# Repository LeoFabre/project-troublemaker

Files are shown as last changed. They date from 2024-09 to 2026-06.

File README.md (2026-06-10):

# 🚨PROJECT TROUBLEMAKER🚨 - ABANDONED, new project coming very soon
### The original dub soundsystem-style, fully digital, open source music preamp, based on ELK Audio OS.

This project is meant to be a fully digital sound system preamp, with a lot of features and a lot of fun to use. 
This would typically be used in a dub sound system control tower, right before the DSPs and power amps.
I am making it for [my own dub sound system](https://linktr.ee/mooncrownsoundsystem), but I am sharing it with the world so that everyone can enjoy and contribute to it.

### **_[Figma design of the front plate (click to open in figma) :](https://www.figma.com/design/a7w33TZh6XjIDETXx0zezs/PROJECT-TROUBLEMAKER?node-id=2-57&t=kPiumWiky9OcTQFE-1)_**
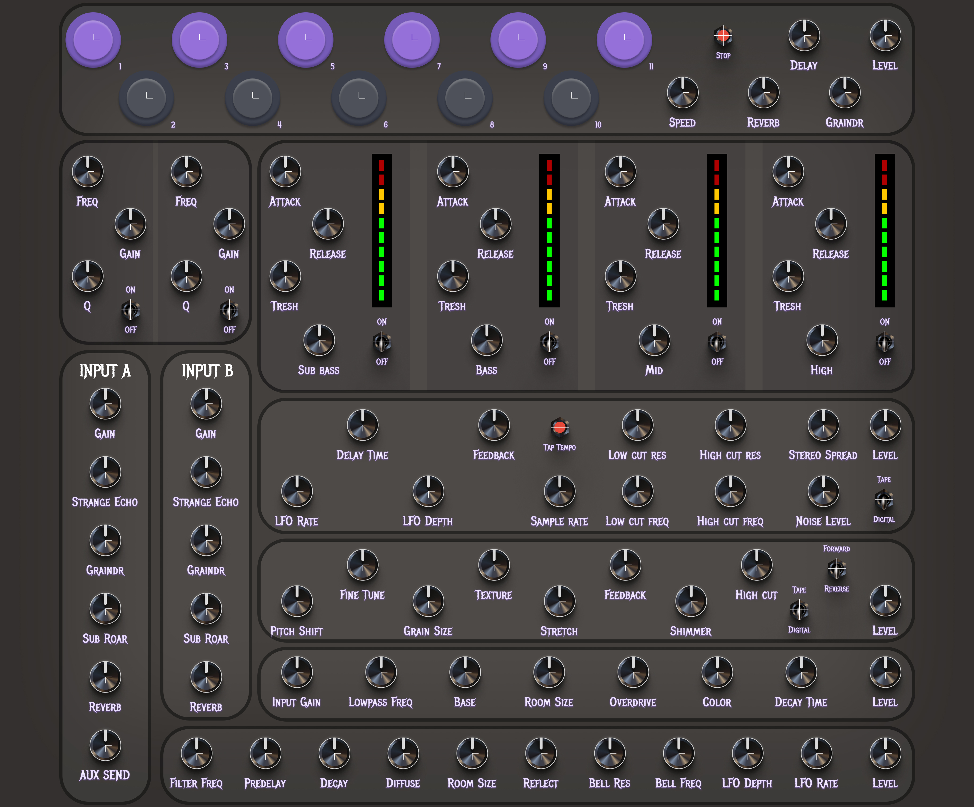
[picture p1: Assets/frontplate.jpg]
(https://www.figma.com/design/a7w33TZh6XjIDETXx0zezs/PROJECT-TROUBLEMAKER?node-id=2-57&t=kPiumWiky9OcTQFE-1)


Please note that this project is still in its early stages, and it is not yet ready for use.
Also, the aim is not to provide a classic preamp to use with a microphone, but rather a preamp to use with a line-level signal, like a CD player, a computer, a synthesizer, etc.
It will NOT provide any protection for your speakers, and also will not split the signal into multiple bands outputs. 

It is meant to be used with a DSP that can handle multiple outputs, and optionally a mixer before it, to get microphone inputs and other line-level inputs.

**At the moment, the inputs and outputs are stereo only**, but more input modes will be added in the future (see Signal Flow section).

# [Software & Hardware stack (Click to open in whimsical)](https://whimsical.com/project-troublemaker-project-diagram-5eJmr8VAKfvCzGg2v3uwR2)
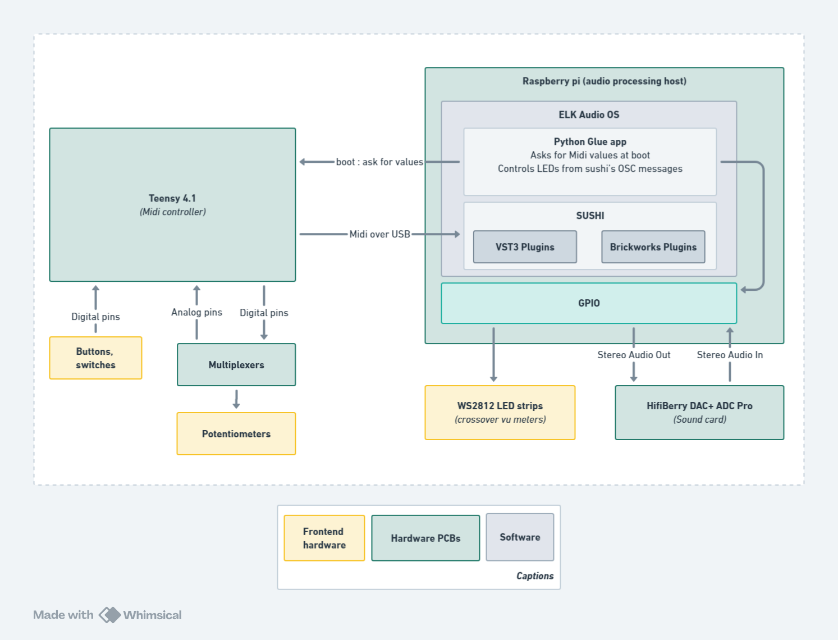
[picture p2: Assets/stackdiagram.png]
(https://whimsical.com/project-troublemaker-project-diagram-5eJmr8VAKfvCzGg2v3uwR2)

Project Troublemaker is based on [ELK Audio OS](https://elk-audio.github.io/elk-docs/html/index.html), which is a Linux-based realtime audio OS that can run VST3 plugins.  
It is **_HIGHLY RECOMMENDED_** to get a grasp of ELK Audio OS before diving into this project.

I use a [Raspberry pi 4 (8GB)](https://www.raspberrypi.com/products/raspberry-pi-4-model-b/) as the main board, 

a [HifiBerry DAC+ ADC Pro](https://www.hifiberry.com/shop/boards/hifiberry-dac-adc-pro/), to get audio I/O,

a [Teensy 4.1](https://www.pjrc.com/store/teensy41.html) as the control board, which acts as a MIDI controller and communicates with the Raspberry Pi via USB.

To build the control panel I use [CD74HC4067 multiplexers](https://www.amazon.fr/ICQUANZX-CD74HC4067-Analogique-Multiplexeur-Num%C3%A9rique/dp/B07VF14YNG), and a lot of [arcade buttons](https://www.smallcab.net/sanwa-obsc-24mm-translucent-pushbutton-purple-p-2462.html), [potentiometers](https://www.amazon.fr/dp/B07B64MWRF?ref=ppx_yo2ov_dt_b_fed_asin_title), [RGB LED sticks](https://fr.aliexpress.com/item/1005006344542138.html), and [switches](https://amazon.fr/dp/B09W4HBXJ7).

The project is meant to be a fully open source project, with all the source code and hardware design files available for free.

**_Because I strongly believe that music is meant to be shared, and music gear should be open source._**

Please feel free to contribute by opening a PR or an issue. 

**_Keep in mind that I am still learning, and that I am doing this project in my free time_**, so I may take some time to get back to you and updates may be slow.

# Featured Plugins (Work in Progress)
- **_[SampleTower](https://github.com/LeoFabre/SampleTower)_** : My JUCE-based VST3 sample player. features 11 fully-loaded-in-RAM sample slots, real-time playback speed control, sample loading from the file system (via config file), sample triggering with a MIDI note, one-shot and loop modes for each sample (via config file), kill button that stops all currently playing samples.
- 2 parametric EQs with bypass switches.
- **_[Moses](https://github.com/LeoFabre/Moses)_** : My fork of [IEM's multiband compressor](https://git.iem.at/audioplugins/IEMPluginSuite/-/tree/master/MultiBandCompressor?ref_type=heads). It is a 4-band SIMD optimized multiband compressor/crossover plugin, featuring cascaded Butterworth, linkwitz-riley filters and Allpass filters, solo&kill switches and master controls.
- **_[Strange Returns](https://github.com/LeoFabre/StrangeReturns-CMake)_** : My fork of JackWithOneEye's [Strange Returns](https://github.com/JackWithOneEye/StrangeReturns) delay plugin. 
- **_[Graindr](https://github.com/LeoFabre/Graindr)_** : My fork of JackWithOneEye's [Graindr](https://github.com/JackWithOneEye/Graindr), dual granular delay plugin.
- **_Parametric Reverb FX_** : A parametric reverb that I have yet to design. The reverb pots on the frontplate are inspired by ableton's reverb plugin, and are subject to change.
- **_Sub Roar FX_** : A classic dub sub bass roar effect based on saturation, and filtering, and reverb. It is only composed of BrickWorks plugins that ELK Audio OS provides, I may or may not make a JUCE version of it in the future.

# [Signal Flow (click to open in whimsical)](https://whimsical.com/project-troublemaker-signal-flow-PksJ2XxrEqBQ8Brrcc3UFW)
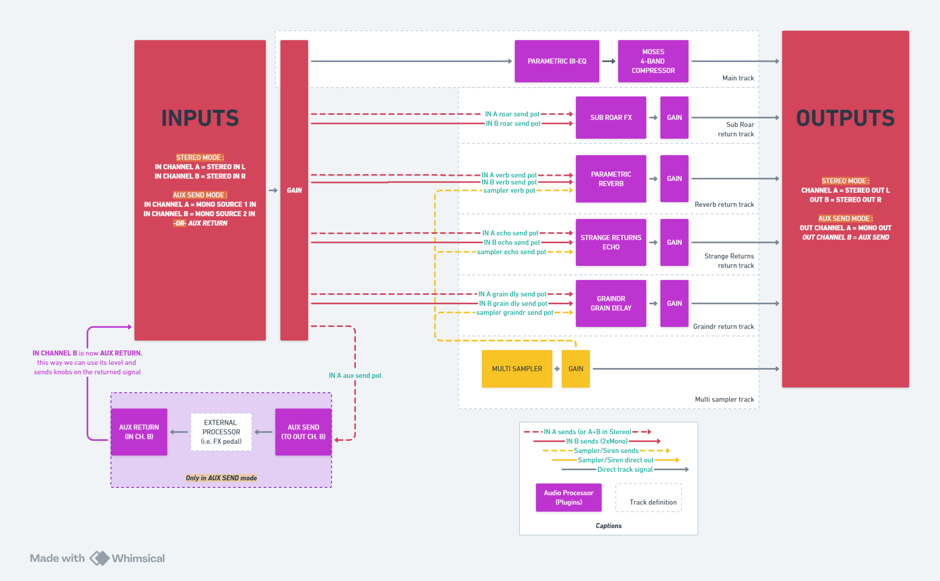
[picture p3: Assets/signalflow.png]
(https://whimsical.com/project-troublemaker-signal-flow-PksJ2XxrEqBQ8Brrcc3UFW)

## Input modes
- **_Stereo mode_**: The default mode, where the HifiBerry is used as a stereo input and output.
- **_Aux send mode_** (to be implemented): The 2 stereo channels of the HifiBerry are split in 2 mono input channels and 2 mono output channels.   
The first mono input channel is used as the main input, the first mono output is used as the main output, the second mono input channel is used as the aux send, and the second mono input channel is used as the aux return.   
This is useful to send the signal to an external effect processor and get it back in the preamp, like a reverb or a delay, and then use the preamp's processing on it.

As of now, the modes are not implemented, and the preamp only works in stereo mode.  
In the future, I will add a switch to select the input mode at boot time (Sushi would then get its processor graph built by the glue app via gRPC instead of the config file).

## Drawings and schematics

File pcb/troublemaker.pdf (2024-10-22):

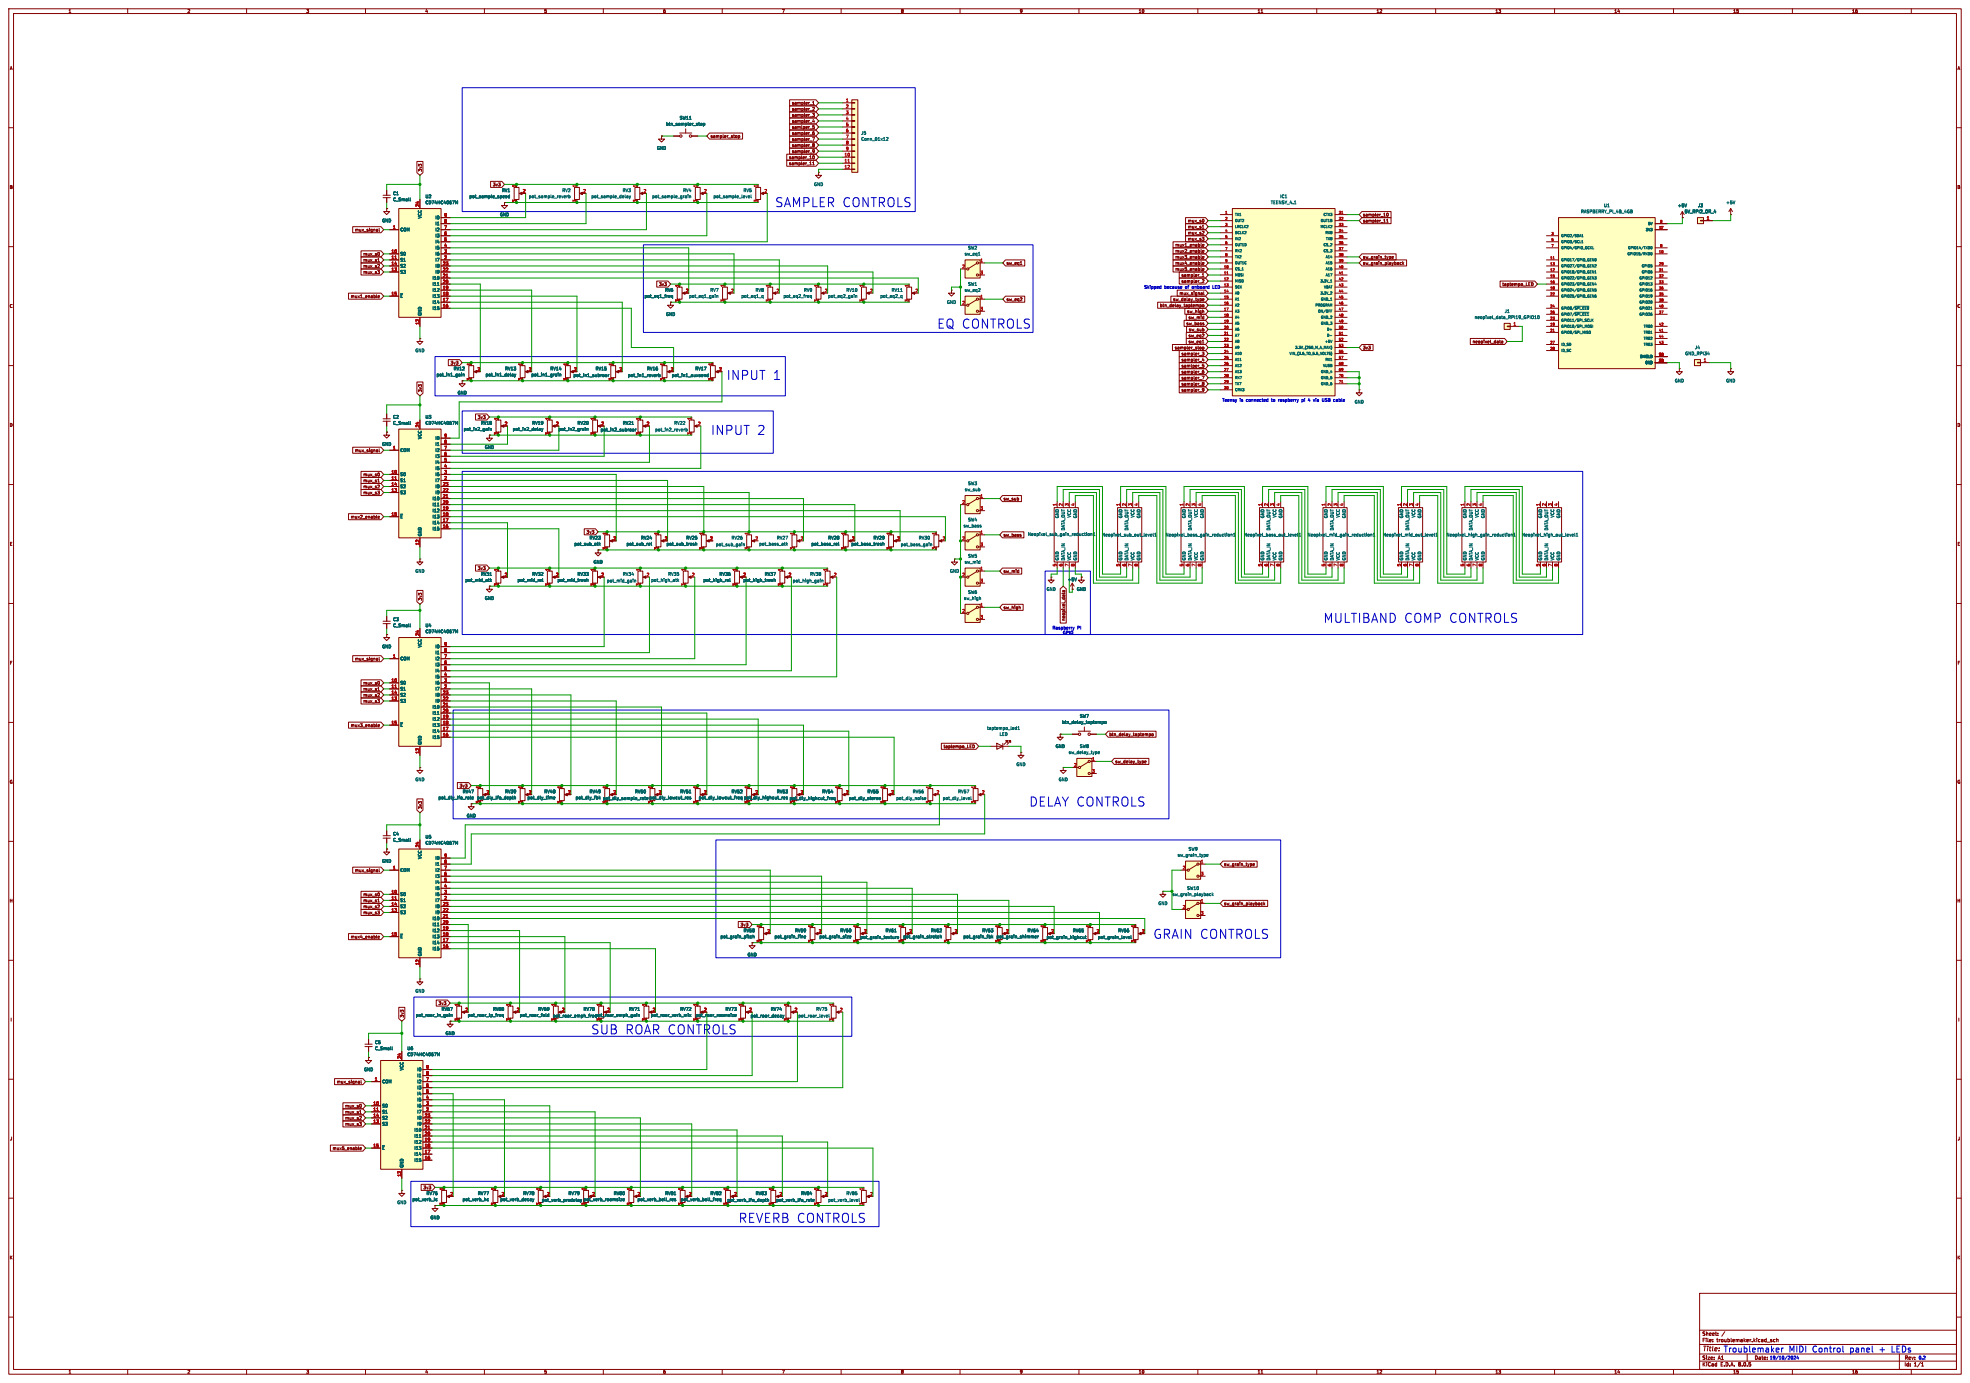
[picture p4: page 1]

Skipped because of onboard LED SUB ROAR CONTROLS

Id: 1/1 Title: File: troublemaker.kicad_sch Sheet: / 1

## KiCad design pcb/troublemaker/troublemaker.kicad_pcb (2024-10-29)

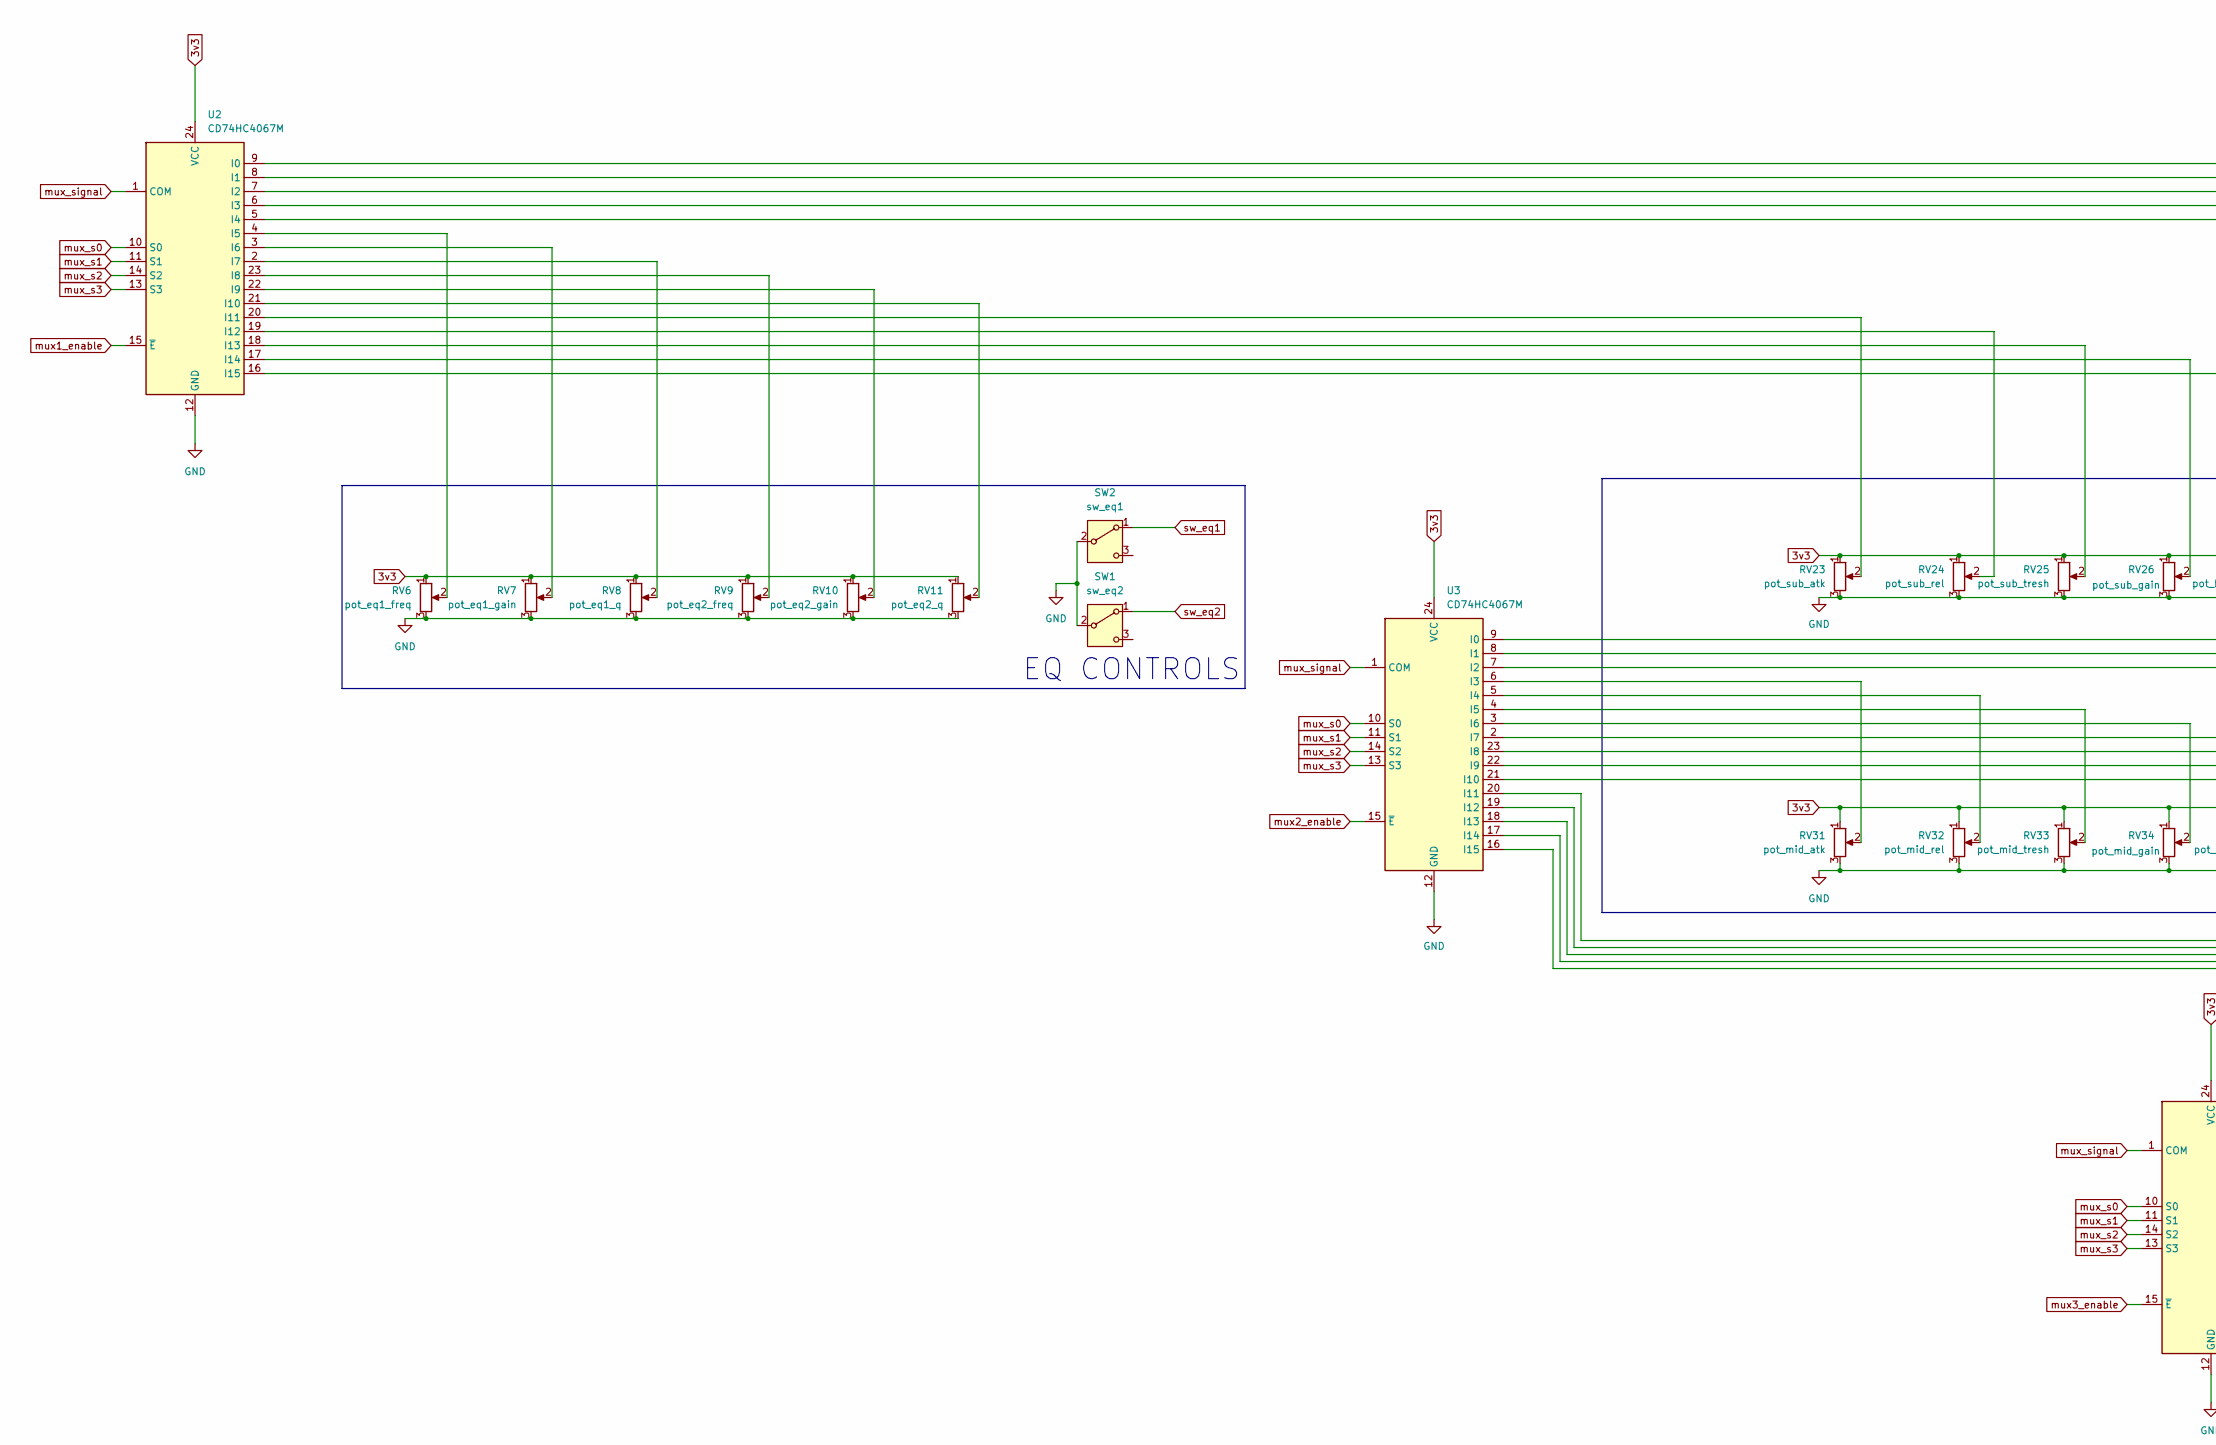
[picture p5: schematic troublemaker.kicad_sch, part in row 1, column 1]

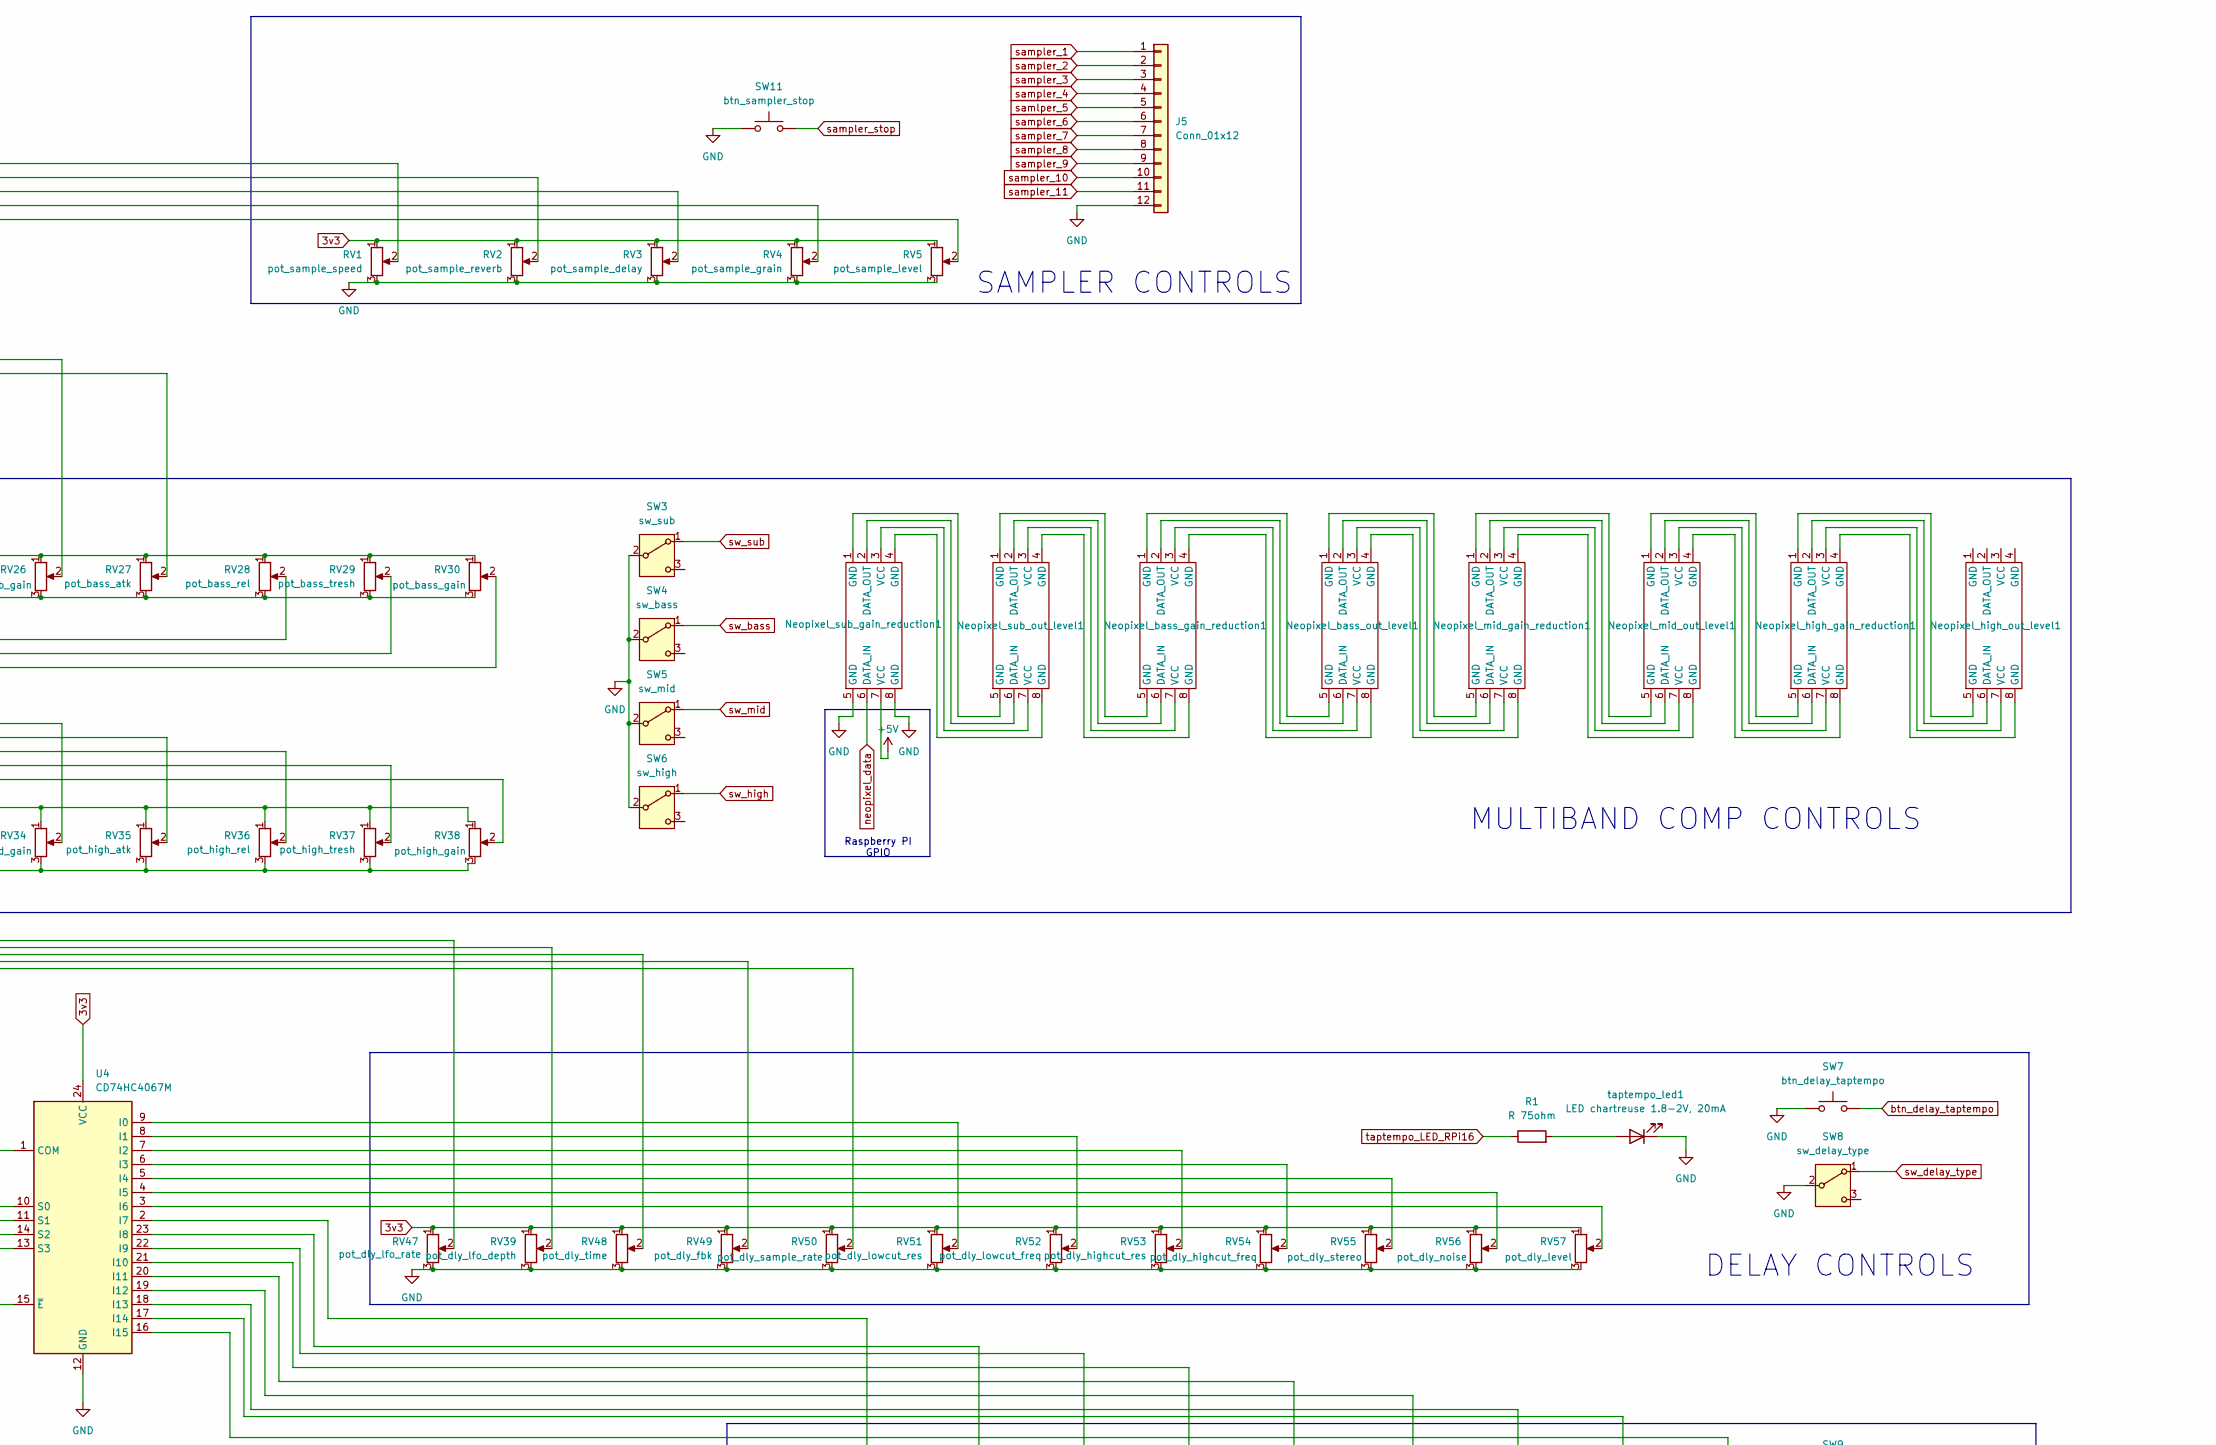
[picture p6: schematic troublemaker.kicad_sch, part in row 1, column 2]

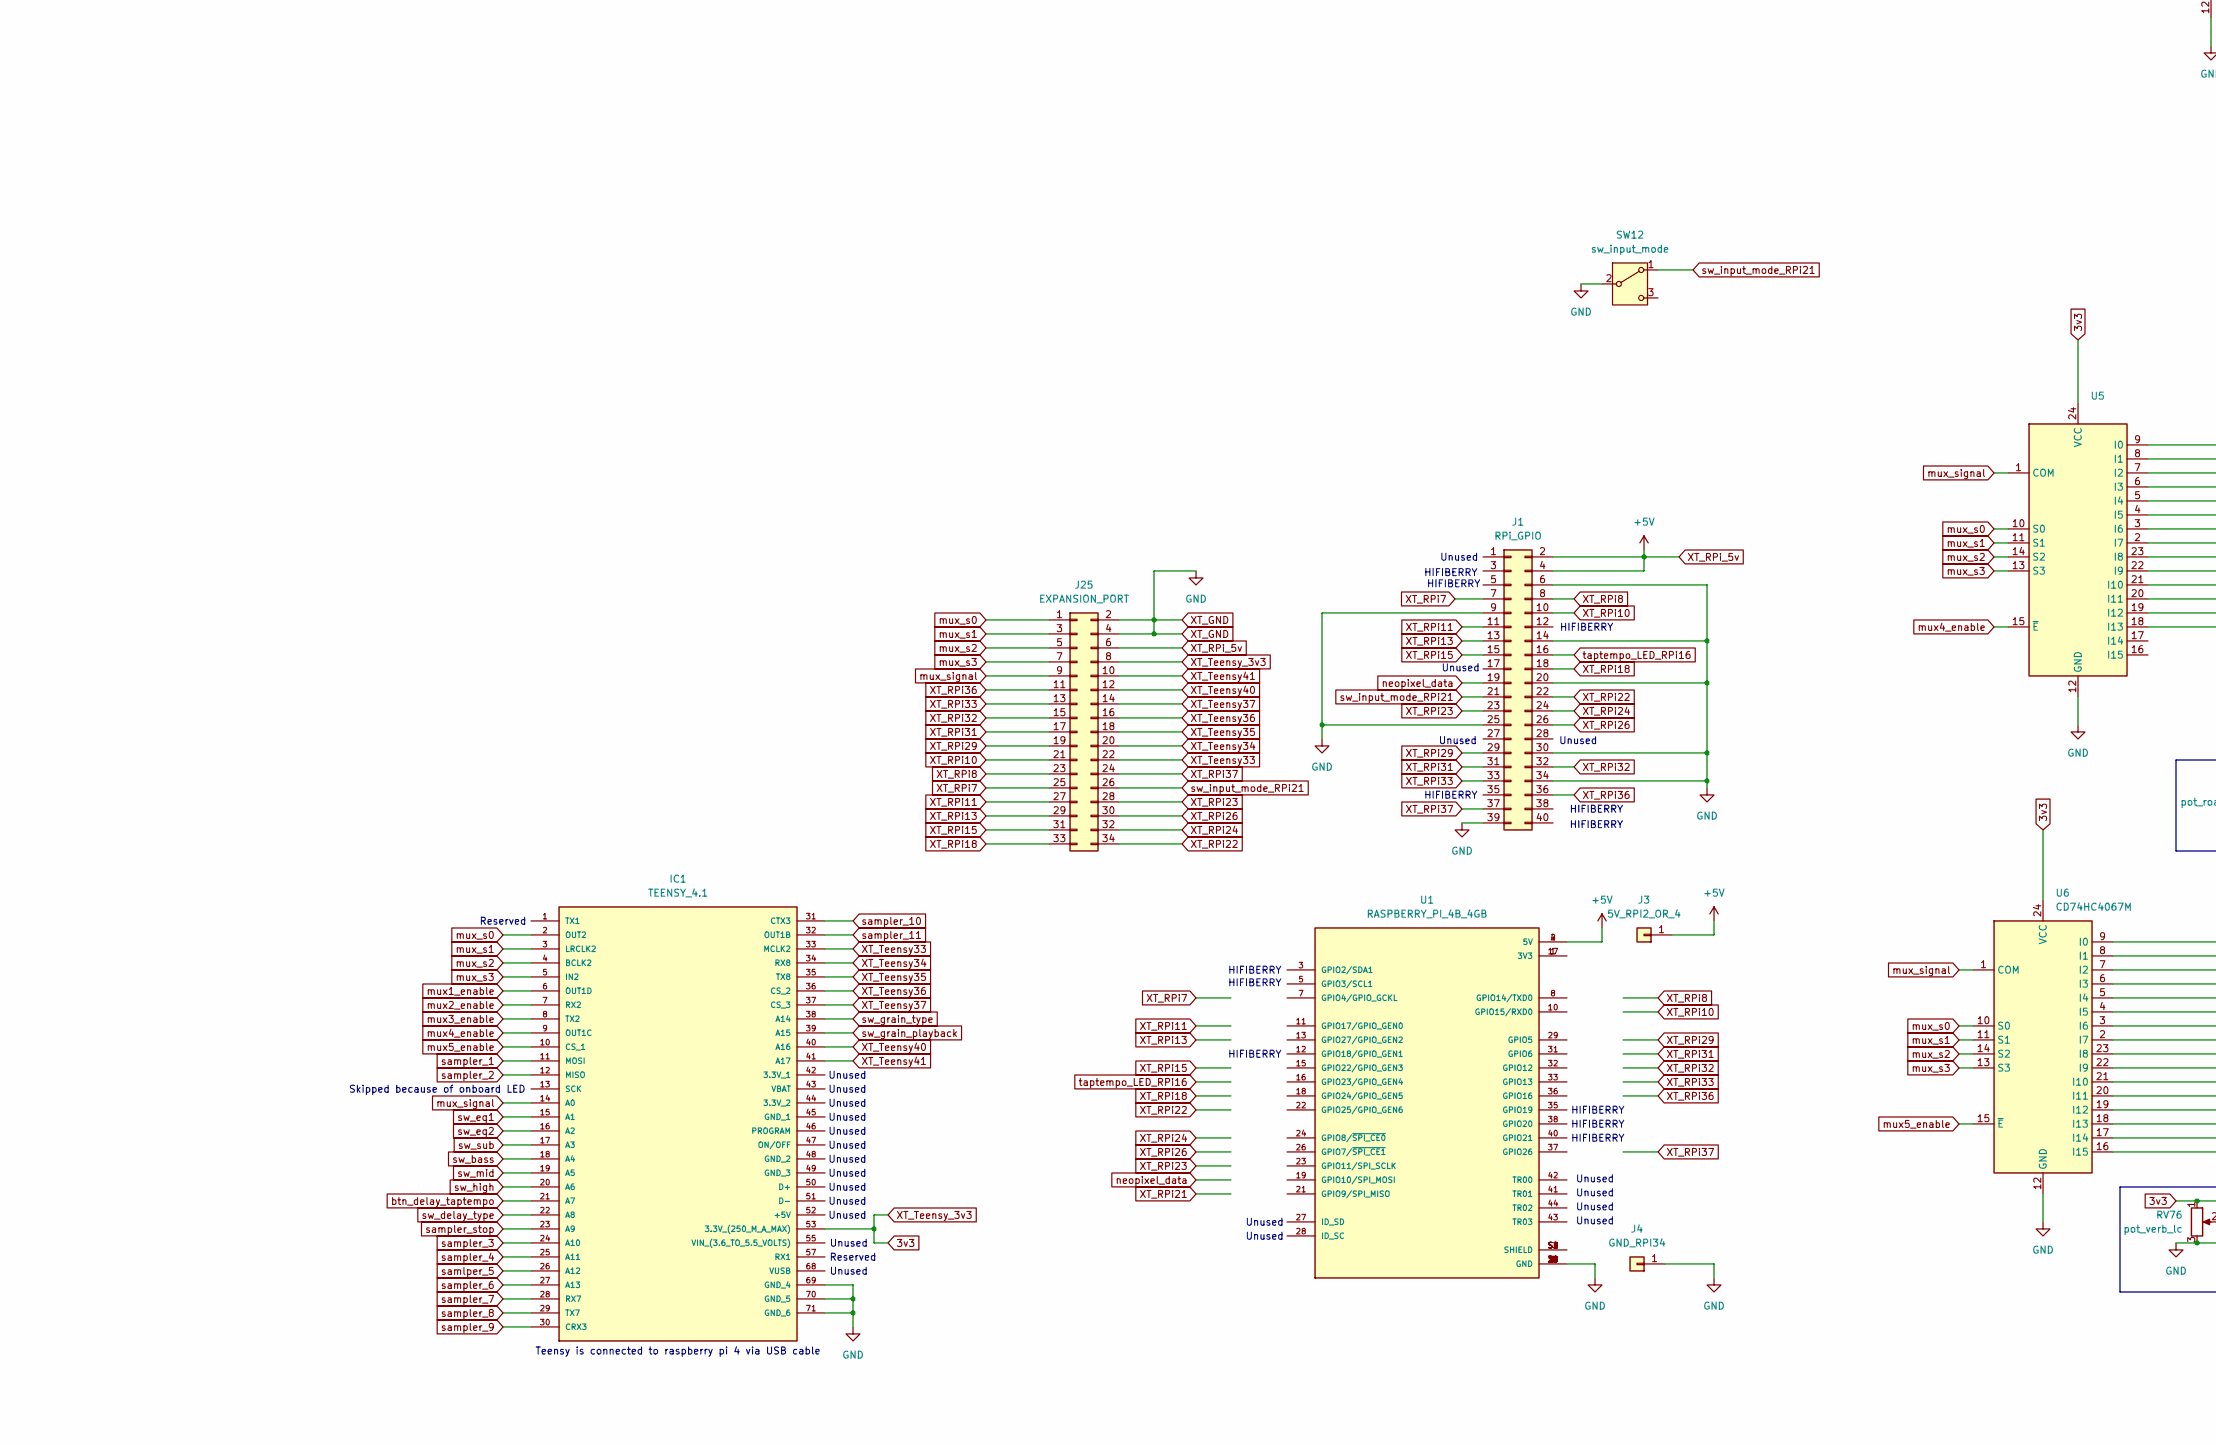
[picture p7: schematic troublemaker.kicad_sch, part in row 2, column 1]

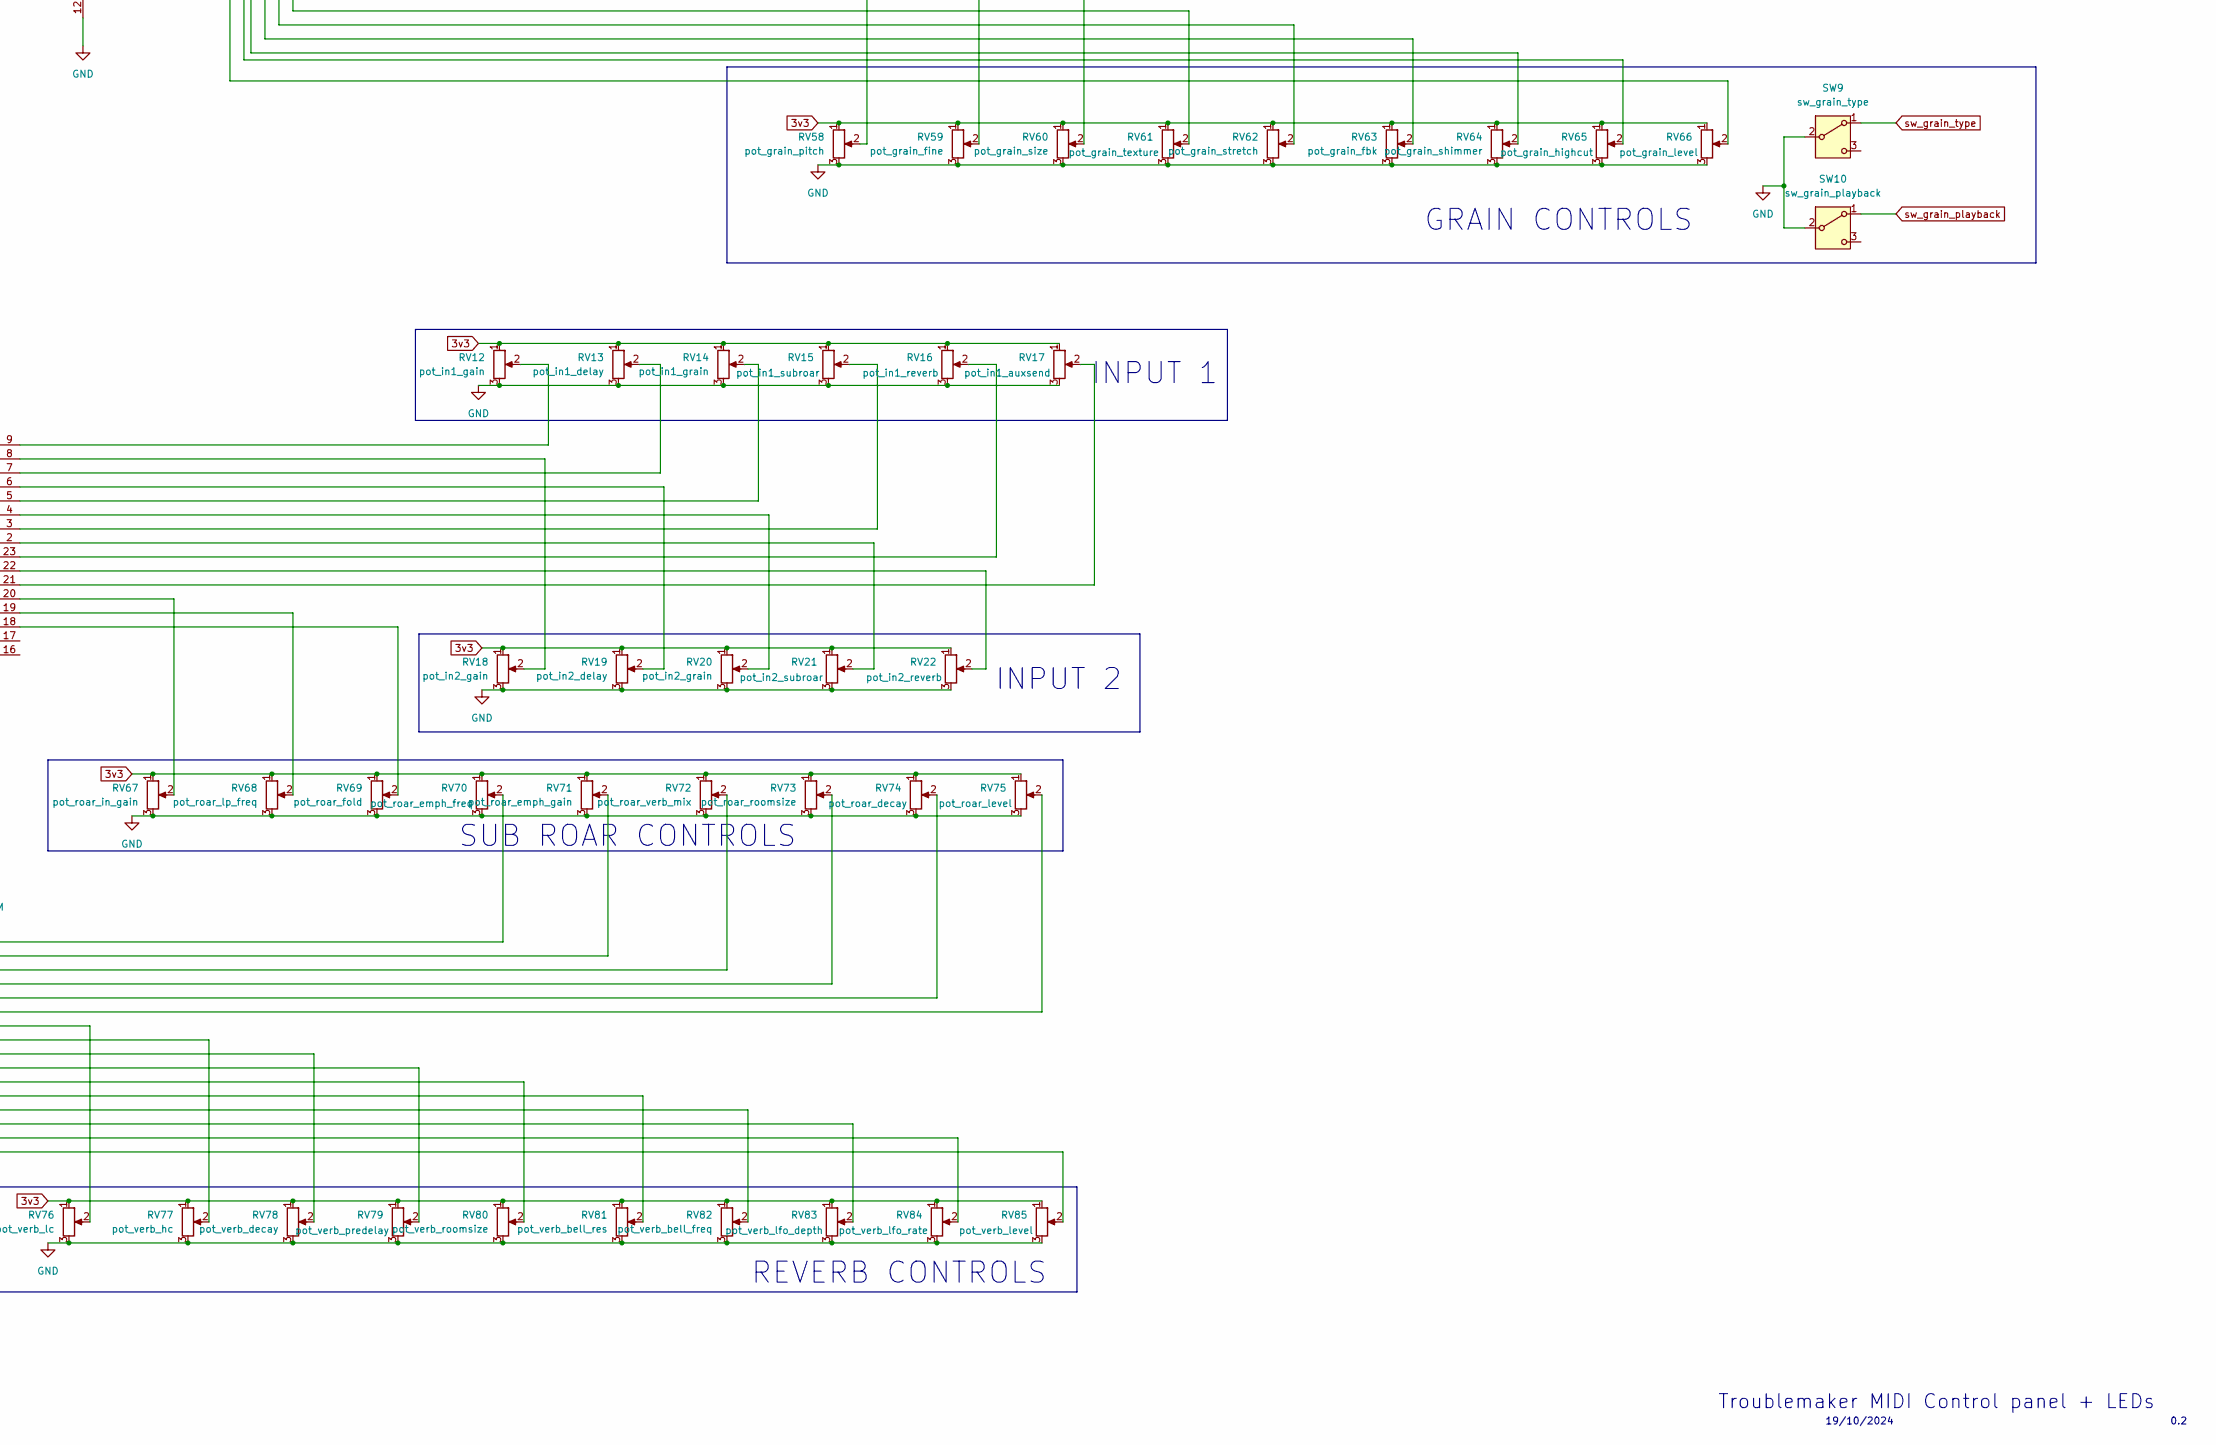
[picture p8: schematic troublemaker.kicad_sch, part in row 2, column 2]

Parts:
IC1: TEENSY_4.1; TEENSY41; Manufacturer_Part_Number TEENSY 4.1
J1: RPi_GPIO; IDC-Header_2x20_P2.54mm_Vertical
J3: 5V_RPI2_OR_4; PinHeader_1x01_P1.00mm_Vertical
J4: GND_RPI34; PinHeader_1x01_P1.00mm_Vertical
J5: Conn_01x12; PinHeader_1x12_P2.00mm_Vertical
J25: EXPANSION_PORT; IDC-Header_2x17_P2.54mm_Vertical
Neopixel_bass_gain_reduction1: Neopixel-8LED
Neopixel_bass_out_level1: Neopixel-8LED
Neopixel_high_gain_reduction1: Neopixel-8LED
Neopixel_high_out_level1: Neopixel-8LED
Neopixel_mid_gain_reduction1: Neopixel-8LED
Neopixel_mid_out_level1: Neopixel-8LED
Neopixel_sub_gain_reduction1: Neopixel-8LED
Neopixel_sub_out_level1: Neopixel-8LED
R1: R 75ohm; R_Axial_DIN0207_L6.3mm_D2.5mm_P10.16mm_Horizontal
RV1: pot_sample_speed; Potentiometer_Alps_RK09K_Single_Vertical
RV2: pot_sample_reverb; Potentiometer_Alps_RK09K_Single_Vertical
RV3: pot_sample_delay; Potentiometer_Alps_RK09K_Single_Vertical
RV4: pot_sample_grain; Potentiometer_Alps_RK09K_Single_Vertical
RV5: pot_sample_level; Potentiometer_Alps_RK09K_Single_Vertical
RV6: pot_eq1_freq; Potentiometer_Alps_RK09K_Single_Vertical
RV7: pot_eq1_gain; Potentiometer_Alps_RK09K_Single_Vertical
RV8: pot_eq1_q; Potentiometer_Alps_RK09K_Single_Vertical
RV9: pot_eq2_freq; Potentiometer_Alps_RK09K_Single_Vertical
RV10: pot_eq2_gain; Potentiometer_Alps_RK09K_Single_Vertical
RV11: pot_eq2_q; Potentiometer_Alps_RK09K_Single_Vertical
RV12: pot_in1_gain; Potentiometer_Alps_RK09K_Single_Vertical
RV13: pot_in1_delay; Potentiometer_Alps_RK09K_Single_Vertical
RV14: pot_in1_grain; Potentiometer_Alps_RK09K_Single_Vertical
RV15: pot_in1_subroar; Potentiometer_Alps_RK09K_Single_Vertical
RV16: pot_in1_reverb; Potentiometer_Alps_RK09K_Single_Vertical
RV17: pot_in1_auxsend; Potentiometer_Alps_RK09K_Single_Vertical
RV18: pot_in2_gain; Potentiometer_Alps_RK09K_Single_Vertical
RV19: pot_in2_delay; Potentiometer_Alps_RK09K_Single_Vertical
RV20: pot_in2_grain; Potentiometer_Alps_RK09K_Single_Vertical
RV21: pot_in2_subroar; Potentiometer_Alps_RK09K_Single_Vertical
RV22: pot_in2_reverb; Potentiometer_Alps_RK09K_Single_Vertical
RV23: pot_sub_atk; Potentiometer_Alps_RK09K_Single_Vertical
RV24: pot_sub_rel; Potentiometer_Alps_RK09K_Single_Vertical
RV25: pot_sub_tresh; Potentiometer_Alps_RK09K_Single_Vertical
RV26: pot_sub_gain; Potentiometer_Alps_RK09K_Single_Vertical
RV27: pot_bass_atk; Potentiometer_Alps_RK09K_Single_Vertical
RV28: pot_bass_rel; Potentiometer_Alps_RK09K_Single_Vertical
RV29: pot_bass_tresh; Potentiometer_Alps_RK09K_Single_Vertical
RV30: pot_bass_gain; Potentiometer_Alps_RK09K_Single_Vertical
RV31: pot_mid_atk; Potentiometer_Alps_RK09K_Single_Vertical
RV32: pot_mid_rel; Potentiometer_Alps_RK09K_Single_Vertical
RV33: pot_mid_tresh; Potentiometer_Alps_RK09K_Single_Vertical
RV34: pot_mid_gain; Potentiometer_Alps_RK09K_Single_Vertical
RV35: pot_high_atk; Potentiometer_Alps_RK09K_Single_Vertical
RV36: pot_high_rel; Potentiometer_Alps_RK09K_Single_Vertical
RV37: pot_high_tresh; Potentiometer_Alps_RK09K_Single_Vertical
RV38: pot_high_gain; Potentiometer_Alps_RK09K_Single_Vertical
RV39: pot_dly_lfo_depth; Potentiometer_Alps_RK09K_Single_Vertical
RV47: pot_dly_lfo_rate; Potentiometer_Alps_RK09K_Single_Vertical
RV48: pot_dly_time; Potentiometer_Alps_RK09K_Single_Vertical
RV49: pot_dly_fbk; Potentiometer_Alps_RK09K_Single_Vertical
RV50: pot_dly_sample_rate; Potentiometer_Alps_RK09K_Single_Vertical
RV51: pot_dly_lowcut_res; Potentiometer_Alps_RK09K_Single_Vertical
RV52: pot_dly_lowcut_freq; Potentiometer_Alps_RK09K_Single_Vertical
RV53: pot_dly_highcut_res; Potentiometer_Alps_RK09K_Single_Vertical
RV54: pot_dly_highcut_freq; Potentiometer_Alps_RK09K_Single_Vertical
RV55: pot_dly_stereo; Potentiometer_Alps_RK09K_Single_Vertical
RV56: pot_dly_noise; Potentiometer_Alps_RK09K_Single_Vertical
RV57: pot_dly_level; Potentiometer_Alps_RK09K_Single_Vertical
RV58: pot_grain_pitch; Potentiometer_Alps_RK09K_Single_Vertical
RV59: pot_grain_fine; Potentiometer_Alps_RK09K_Single_Vertical
RV60: pot_grain_size; Potentiometer_Alps_RK09K_Single_Vertical
RV61: pot_grain_texture; Potentiometer_Alps_RK09K_Single_Vertical
RV62: pot_grain_stretch; Potentiometer_Alps_RK09K_Single_Vertical
RV63: pot_grain_fbk; Potentiometer_Alps_RK09K_Single_Vertical
RV64: pot_grain_shimmer; Potentiometer_Alps_RK09K_Single_Vertical
RV65: pot_grain_highcut; Potentiometer_Alps_RK09K_Single_Vertical
RV66: pot_grain_level; Potentiometer_Alps_RK09K_Single_Vertical
RV67: pot_roar_in_gain; Potentiometer_Alps_RK09K_Single_Vertical
RV68: pot_roar_lp_freq; Potentiometer_Alps_RK09K_Single_Vertical
RV69: pot_roar_fold; Potentiometer_Alps_RK09K_Single_Vertical
RV70: pot_roar_emph_freq; Potentiometer_Alps_RK09K_Single_Vertical
RV71: pot_roar_emph_gain; Potentiometer_Alps_RK09K_Single_Vertical
RV72: pot_roar_verb_mix; Potentiometer_Alps_RK09K_Single_Vertical
RV73: pot_roar_roomsize; Potentiometer_Alps_RK09K_Single_Vertical
RV74: pot_roar_decay; Potentiometer_Alps_RK09K_Single_Vertical
RV75: pot_roar_level; Potentiometer_Alps_RK09K_Single_Vertical
RV76: pot_verb_lc; Potentiometer_Alps_RK09K_Single_Vertical
RV77: pot_verb_hc; Potentiometer_Alps_RK09K_Single_Vertical
RV78: pot_verb_decay; Potentiometer_Alps_RK09K_Single_Vertical
RV79: pot_verb_predelay; Potentiometer_Alps_RK09K_Single_Vertical
RV80: pot_verb_roomsize; Potentiometer_Alps_RK09K_Single_Vertical
RV81: pot_verb_bell_res; Potentiometer_Alps_RK09K_Single_Vertical
RV82: pot_verb_bell_freq; Potentiometer_Alps_RK09K_Single_Vertical
RV83: pot_verb_lfo_depth; Potentiometer_Alps_RK09K_Single_Vertical
RV84: pot_verb_lfo_rate; Potentiometer_Alps_RK09K_Single_Vertical
RV85: pot_verb_level; Potentiometer_Alps_RK09K_Single_Vertical
SW1: sw_eq2; SW_SPDT_red_leozor
SW2: sw_eq1; SW_SPDT_red_leozor
SW3: sw_sub; SW_SPDT_red_leozor
SW4: sw_bass; SW_SPDT_red_leozor
SW5: sw_mid; SW_SPDT_red_leozor
SW6: sw_high; SW_SPDT_red_leozor
SW7: btn_delay_taptempo; arcade_service_button_leozor
SW8: sw_delay_type; SW_SPDT_red_leozor
SW9: sw_grain_type; SW_SPDT_red_leozor
SW10: sw_grain_playback; SW_SPDT_red_leozor
SW11: btn_sampler_stop; arcade_service_button_leozor
SW12: sw_input_mode; SW_SPDT_red_leozor
U1: RASPBERRY_PI_4B_4GB; MODULE_RASPBERRY_PI_4B_4GB; PARTREV 4
U2, U3, U4, U5, U6: CD74HC4067M; Breakout_HC4067_PTH_Only
taptempo_led1: LED chartreuse 1.8-2V, 20mA; LED_D3.0mm

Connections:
3v3: IC1.53 (3.3V_(250_M_A_MAX)), J25.8, RV1.1, RV2.1, RV3.1, RV4.1, RV5.1, RV6.1, RV7.1, RV8.1, RV9.1, RV10.1, RV11.1, RV12.1, RV13.1, RV14.1, RV15.1, RV16.1, RV17.1, RV18.1, RV19.1, RV20.1, RV21.1, RV22.1, RV23.1, RV24.1, RV25.1, RV26.1, RV27.1, RV28.1, RV29.1, RV30.1, RV31.1, RV32.1, RV33.1, RV34.1, RV35.1, RV36.1, RV37.1, RV38.1, RV39.1, RV47.1, RV48.1, RV49.1, RV50.1, RV51.1, RV52.1, RV53.1, RV54.1, RV55.1, RV56.1, RV57.1, RV58.1, RV59.1, RV60.1, RV61.1, RV62.1, RV63.1, RV64.1, RV65.1, RV66.1, RV67.1, RV68.1, RV69.1, RV70.1, RV71.1, RV72.1, RV73.1, RV74.1, RV75.1, RV76.1, RV77.1, RV78.1, RV79.1, RV80.1, RV81.1, RV82.1, RV83.1, RV84.1, RV85.1, U2.24 (VCC), U3.24 (VCC), U4.24 (VCC), U5.24 (VCC), U6.24 (VCC)
unnamed: Neopixel_bass_gain_reduction1.6 (DATA_IN), Neopixel_sub_out_level1.2 (DATA_OUT)
unnamed: Neopixel_bass_gain_reduction1.2 (DATA_OUT), Neopixel_bass_out_level1.6 (DATA_IN)
unnamed: Neopixel_bass_gain_reduction1.1 (GND), Neopixel_bass_out_level1.5 (GND)
unnamed: Neopixel_bass_gain_reduction1.4 (GND), Neopixel_bass_out_level1.8 (GND)
unnamed: Neopixel_bass_gain_reduction1.5 (GND), Neopixel_sub_out_level1.1 (GND)
unnamed: Neopixel_bass_gain_reduction1.8 (GND), Neopixel_sub_out_level1.4 (GND)
unnamed: Neopixel_bass_gain_reduction1.3 (VCC), Neopixel_bass_out_level1.7 (VCC)
unnamed: Neopixel_bass_gain_reduction1.7 (VCC), Neopixel_sub_out_level1.3 (VCC)
unnamed: Neopixel_bass_out_level1.2 (DATA_OUT), Neopixel_mid_gain_reduction1.6 (DATA_IN)
unnamed: Neopixel_bass_out_level1.1 (GND), Neopixel_mid_gain_reduction1.5 (GND)
unnamed: Neopixel_bass_out_level1.4 (GND), Neopixel_mid_gain_reduction1.8 (GND)
unnamed: Neopixel_bass_out_level1.3 (VCC), Neopixel_mid_gain_reduction1.7 (VCC)
unnamed: Neopixel_high_gain_reduction1.6 (DATA_IN), Neopixel_mid_out_level1.2 (DATA_OUT)
unnamed: Neopixel_high_gain_reduction1.2 (DATA_OUT), Neopixel_high_out_level1.6 (DATA_IN)
unnamed: Neopixel_high_gain_reduction1.1 (GND), Neopixel_high_out_level1.5 (GND)
unnamed: Neopixel_high_gain_reduction1.4 (GND), Neopixel_high_out_level1.8 (GND)
unnamed: Neopixel_high_gain_reduction1.5 (GND), Neopixel_mid_out_level1.1 (GND)
unnamed: Neopixel_high_gain_reduction1.8 (GND), Neopixel_mid_out_level1.4 (GND)
unnamed: Neopixel_high_gain_reduction1.3 (VCC), Neopixel_high_out_level1.7 (VCC)
unnamed: Neopixel_high_gain_reduction1.7 (VCC), Neopixel_mid_out_level1.3 (VCC)
unnamed: Neopixel_mid_gain_reduction1.2 (DATA_OUT), Neopixel_mid_out_level1.6 (DATA_IN)
unnamed: Neopixel_mid_gain_reduction1.1 (GND), Neopixel_mid_out_level1.5 (GND)
unnamed: Neopixel_mid_gain_reduction1.4 (GND), Neopixel_mid_out_level1.8 (GND)
unnamed: Neopixel_mid_gain_reduction1.3 (VCC), Neopixel_mid_out_level1.7 (VCC)
unnamed: Neopixel_sub_gain_reduction1.2 (DATA_OUT), Neopixel_sub_out_level1.6 (DATA_IN)
unnamed: Neopixel_sub_gain_reduction1.1 (GND), Neopixel_sub_out_level1.5 (GND)
unnamed: Neopixel_sub_gain_reduction1.4 (GND), Neopixel_sub_out_level1.8 (GND)
unnamed: Neopixel_sub_gain_reduction1.3 (VCC), Neopixel_sub_out_level1.7 (VCC)
unnamed: U1.1 (3V3), U1.17 (3V3)
unnamed: U1.S1 (SHIELD), U1.S2 (SHIELD), U1.S3 (SHIELD), U1.S4 (SHIELD)
unnamed: RV1.2, U2.9 (I0)
unnamed: RV2.2, U2.8 (I1)
unnamed: RV3.2, U2.7 (I2)
unnamed: RV4.2, U2.6 (I3)
unnamed: RV5.2, U2.5 (I4)
unnamed: RV6.2, U2.4 (I5)
unnamed: RV7.2, U2.3 (I6)
unnamed: RV8.2, U2.2 (I7)
unnamed: RV9.2, U2.23 (I8)
unnamed: RV10.2, U2.22 (I9)
unnamed: RV11.2, U2.21 (I10)
unnamed: RV23.2, U2.20 (I11)
unnamed: RV24.2, U2.19 (I12)
unnamed: RV25.2, U2.18 (I13)
unnamed: RV26.2, U2.17 (I14)
unnamed: RV27.2, U2.16 (I15)
unnamed: RV28.2, U3.9 (I0)
unnamed: RV29.2, U3.8 (I1)
unnamed: RV30.2, U3.7 (I2)
unnamed: RV31.2, U3.6 (I3)
unnamed: RV32.2, U3.5 (I4)
unnamed: RV33.2, U3.4 (I5)
unnamed: RV34.2, U3.3 (I6)
unnamed: RV35.2, U3.2 (I7)
unnamed: RV36.2, U3.23 (I8)
unnamed: RV37.2, U3.22 (I9)
unnamed: RV38.2, U3.21 (I10)
unnamed: RV47.2, U3.20 (I11)
unnamed: RV39.2, U3.19 (I12)
unnamed: RV48.2, U3.18 (I13)
unnamed: RV49.2, U3.17 (I14)
unnamed: RV50.2, U3.16 (I15)
unnamed: RV51.2, U4.9 (I0)
unnamed: RV52.2, U4.8 (I1)
unnamed: RV53.2, U4.7 (I2)
unnamed: RV54.2, U4.6 (I3)
unnamed: RV55.2, U4.5 (I4)
unnamed: RV56.2, U4.4 (I5)
unnamed: RV57.2, U4.3 (I6)
unnamed: RV58.2, U4.2 (I7)
unnamed: RV59.2, U4.23 (I8)
unnamed: RV60.2, U4.22 (I9)
unnamed: RV61.2, U4.21 (I10)
unnamed: RV62.2, U4.20 (I11)
unnamed: RV63.2, U4.19 (I12)
unnamed: RV64.2, U4.18 (I13)
unnamed: RV65.2, U4.17 (I14)
unnamed: RV66.2, U4.16 (I15)
unnamed: RV12.2, U5.9 (I0)
unnamed: RV18.2, U5.8 (I1)
unnamed: RV13.2, U5.7 (I2)
unnamed: RV19.2, U5.6 (I3)
unnamed: RV14.2, U5.5 (I4)
unnamed: RV20.2, U5.4 (I5)
unnamed: RV15.2, U5.3 (I6)
unnamed: RV21.2, U5.2 (I7)
unnamed: RV16.2, U5.23 (I8)
unnamed: RV22.2, U5.22 (I9)
unnamed: RV17.2, U5.21 (I10)
unnamed: RV67.2, U5.20 (I11)
unnamed: RV68.2, U5.19 (I12)
unnamed: RV69.2, U5.18 (I13)
unnamed: RV70.2, U6.9 (I0)
unnamed: RV71.2, U6.8 (I1)
unnamed: RV72.2, U6.7 (I2)
unnamed: RV73.2, U6.6 (I3)
unnamed: RV74.2, U6.5 (I4)
unnamed: RV75.2, U6.4 (I5)
unnamed: RV76.2, U6.3 (I6)
unnamed: RV77.2, U6.2 (I7)
unnamed: RV78.2, U6.23 (I8)
unnamed: RV79.2, U6.22 (I9)
unnamed: RV80.2, U6.21 (I10)
unnamed: RV81.2, U6.20 (I11)
unnamed: RV82.2, U6.19 (I12)
unnamed: RV83.2, U6.18 (I13)
unnamed: RV84.2, U6.17 (I14)
unnamed: RV85.2, U6.16 (I15)
unnamed: R1.2, taptempo_led1.2 (A)
XT_GND: IC1.69 (GND_4), IC1.70 (GND_5), IC1.71 (GND_6), J1.6, J1.9, J1.14, J1.20, J1.25, J1.30, J1.34, J1.39, J4.1, J5.12, J25.2, J25.4, Neopixel_sub_gain_reduction1.5 (GND), Neopixel_sub_gain_reduction1.8 (GND), RV1.3, RV2.3, RV3.3, RV4.3, RV5.3, RV6.3, RV7.3, RV8.3, RV9.3, RV10.3, RV11.3, RV12.3, RV13.3, RV14.3, RV15.3, RV16.3, RV17.3, RV18.3, RV19.3, RV20.3, RV21.3, RV22.3, RV23.3, RV24.3, RV25.3, RV26.3, RV27.3, RV28.3, RV29.3, RV30.3, RV31.3, RV32.3, RV33.3, RV34.3, RV35.3, RV36.3, RV37.3, RV38.3, RV39.3, RV47.3, RV48.3, RV49.3, RV50.3, RV51.3, RV52.3, RV53.3, RV54.3, RV55.3, RV56.3, RV57.3, RV58.3, RV59.3, RV60.3, RV61.3, RV62.3, RV63.3, RV64.3, RV65.3, RV66.3, RV67.3, RV68.3, RV69.3, RV70.3, RV71.3, RV72.3, RV73.3, RV74.3, RV75.3, RV76.3, RV77.3, RV78.3, RV79.3, RV80.3, RV81.3, RV82.3, RV83.3, RV84.3, RV85.3, SW1.2 (B), SW2.2 (B), SW3.2 (B), SW4.2 (B), SW5.2 (B), SW6.2 (B), SW7.1, SW8.2 (B), SW9.2 (B), SW10.2 (B), SW11.1, SW12.2 (B), U1.6 (GND), U1.9 (GND), U1.14 (GND), U1.20 (GND), U1.25 (GND), U1.30 (GND), U1.34 (GND), U1.39 (GND), U2.12 (GND), U3.12 (GND), U4.12 (GND), U5.12 (GND), U6.12 (GND), taptempo_led1.1 (K); also elsewhere on the board
XT_RPi7: J1.7, J25.25
XT_RPi8: J1.8, J25.23
XT_RPi10: J1.10, J25.21
XT_RPi11: J1.11, J25.27
XT_RPi13: J1.13, J25.29
XT_RPi15: J1.15, J25.31
XT_RPi18: J1.18, J25.33
XT_RPi22: J1.22, J25.34
XT_RPi23: J1.23, J25.28
XT_RPi24: J1.24, J25.32
XT_RPi26: J1.26, J25.30
XT_RPi29: J1.29, J25.19
XT_RPi31: J1.31, J25.17
XT_RPi32: J1.32, J25.15
XT_RPi33: J1.33, J25.13
XT_RPi36: J1.36, J25.11
XT_RPi37: J1.37, J25.24
XT_RPi_5v: J1.2, J1.4, J3.1, J25.6, Neopixel_sub_gain_reduction1.7 (VCC), U1.2 (5V), U1.4 (5V); also elsewhere on the board
XT_Teensy33: IC1.33 (MCLK2), J25.22
XT_Teensy34: IC1.34 (RX8), J25.20
XT_Teensy35: IC1.35 (TX8), J25.18
XT_Teensy36: IC1.36 (CS_2), J25.16
XT_Teensy37: IC1.37 (CS_3), J25.14
XT_Teensy40: IC1.40 (A16), J25.12
XT_Teensy41: IC1.41 (A17), J25.10
btn_delay_taptempo: IC1.21 (A7), SW7.2
mux1_enable: IC1.6 (OUT1D), U2.15 (~E)
mux2_enable: IC1.7 (RX2), U3.15 (~E)
mux3_enable: IC1.8 (TX2), U4.15 (~E)
mux4_enable: IC1.9 (OUT1C), U5.15 (~E)
mux5_enable: IC1.10 (CS_1), U6.15 (~E)
mux_s0: IC1.2 (OUT2), J25.1, U2.10 (S0), U3.10 (S0), U4.10 (S0), U5.10 (S0), U6.10 (S0)
mux_s1: IC1.3 (LRCLK2), J25.3, U2.11 (S1), U3.11 (S1), U4.11 (S1), U5.11 (S1), U6.11 (S1)
mux_s2: IC1.4 (BCLK2), J25.5, U2.14 (S2), U3.14 (S2), U4.14 (S2), U5.14 (S2), U6.14 (S2)
mux_s3: IC1.5 (IN2), J25.7, U2.13 (S3), U3.13 (S3), U4.13 (S3), U5.13 (S3), U6.13 (S3)
mux_signal: IC1.14 (A0), J25.9, U2.1 (COM), U3.1 (COM), U4.1 (COM), U5.1 (COM), U6.1 (COM)
neopixel_data: J1.19, Neopixel_sub_gain_reduction1.6 (DATA_IN)
samlper_5: IC1.26 (A12), J5.5
sampler_1: IC1.11 (MOSI), J5.1
sampler_2: IC1.12 (MISO), J5.2
sampler_3: IC1.24 (A10), J5.3
sampler_4: IC1.25 (A11), J5.4
sampler_6: IC1.27 (A13), J5.6
sampler_7: IC1.28 (RX7), J5.7
sampler_8: IC1.29 (TX7), J5.8
sampler_9: IC1.30 (CRX3), J5.9
sampler_10: IC1.31 (CTX3), J5.10
sampler_11: IC1.32 (OUT1B), J5.11
sampler_stop: IC1.23 (A9), SW11.2
sw_bass: IC1.18 (A4), SW4.1 (A)
sw_delay_type: IC1.22 (A8), SW8.1 (A)
sw_eq1: IC1.15 (A1), SW2.1 (A)
sw_eq2: IC1.16 (A2), SW1.1 (A)
sw_grain_playback: IC1.39 (A15), SW10.1 (A)
sw_grain_type: IC1.38 (A14), SW9.1 (A)
sw_high: IC1.20 (A6), SW6.1 (A)
sw_input_mode_RPi21: J1.21, J25.26, SW12.1 (A)
sw_mid: IC1.19 (A5), SW5.1 (A)
sw_sub: IC1.17 (A3), SW3.1 (A)
taptempo_LED_RPi16: J1.16, R1.1

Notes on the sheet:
HIFIBERRY
Skipped because of onboard LED
Unused
Unused
Troublemaker MIDI Control panel + LEDs
19/10/2024
Raspberry PI GPIO
SAMPLER CONTROLS
DELAY CONTROLS
EQ CONTROLS
Reserved
GRAIN CONTROLS
Teensy is connected to raspberry pi 4 via USB cable
INPUT 2
SUB ROAR CONTROLS
INPUT 1
REVERB CONTROLS
MULTIBAND COMP CONTROLS
0.2

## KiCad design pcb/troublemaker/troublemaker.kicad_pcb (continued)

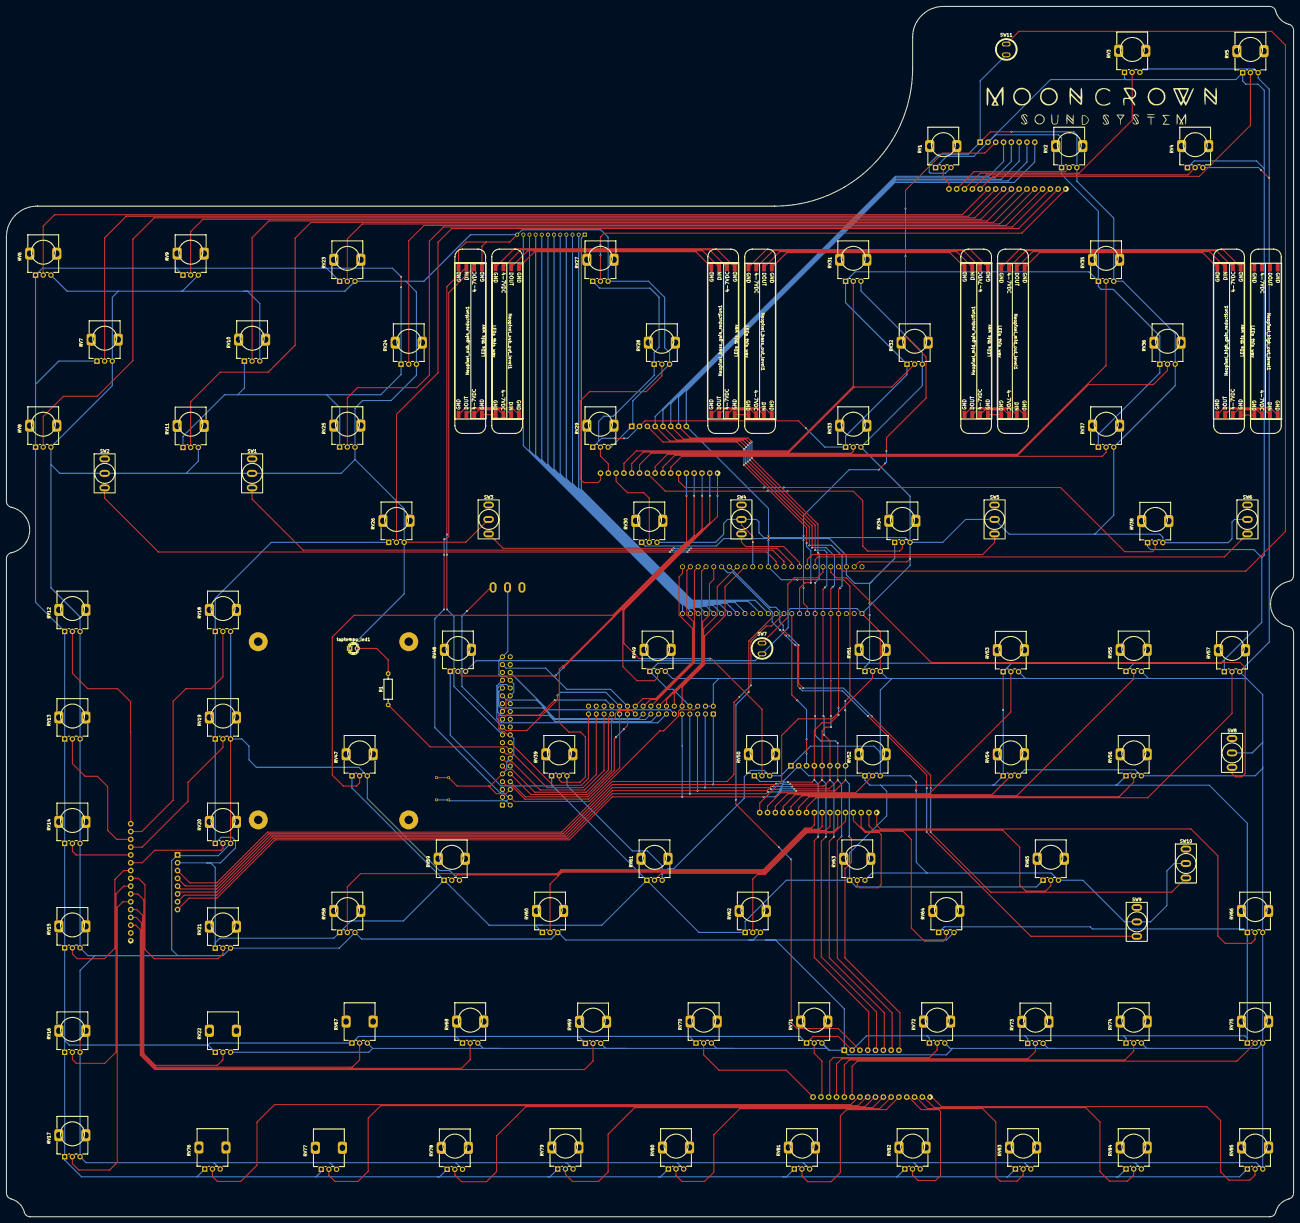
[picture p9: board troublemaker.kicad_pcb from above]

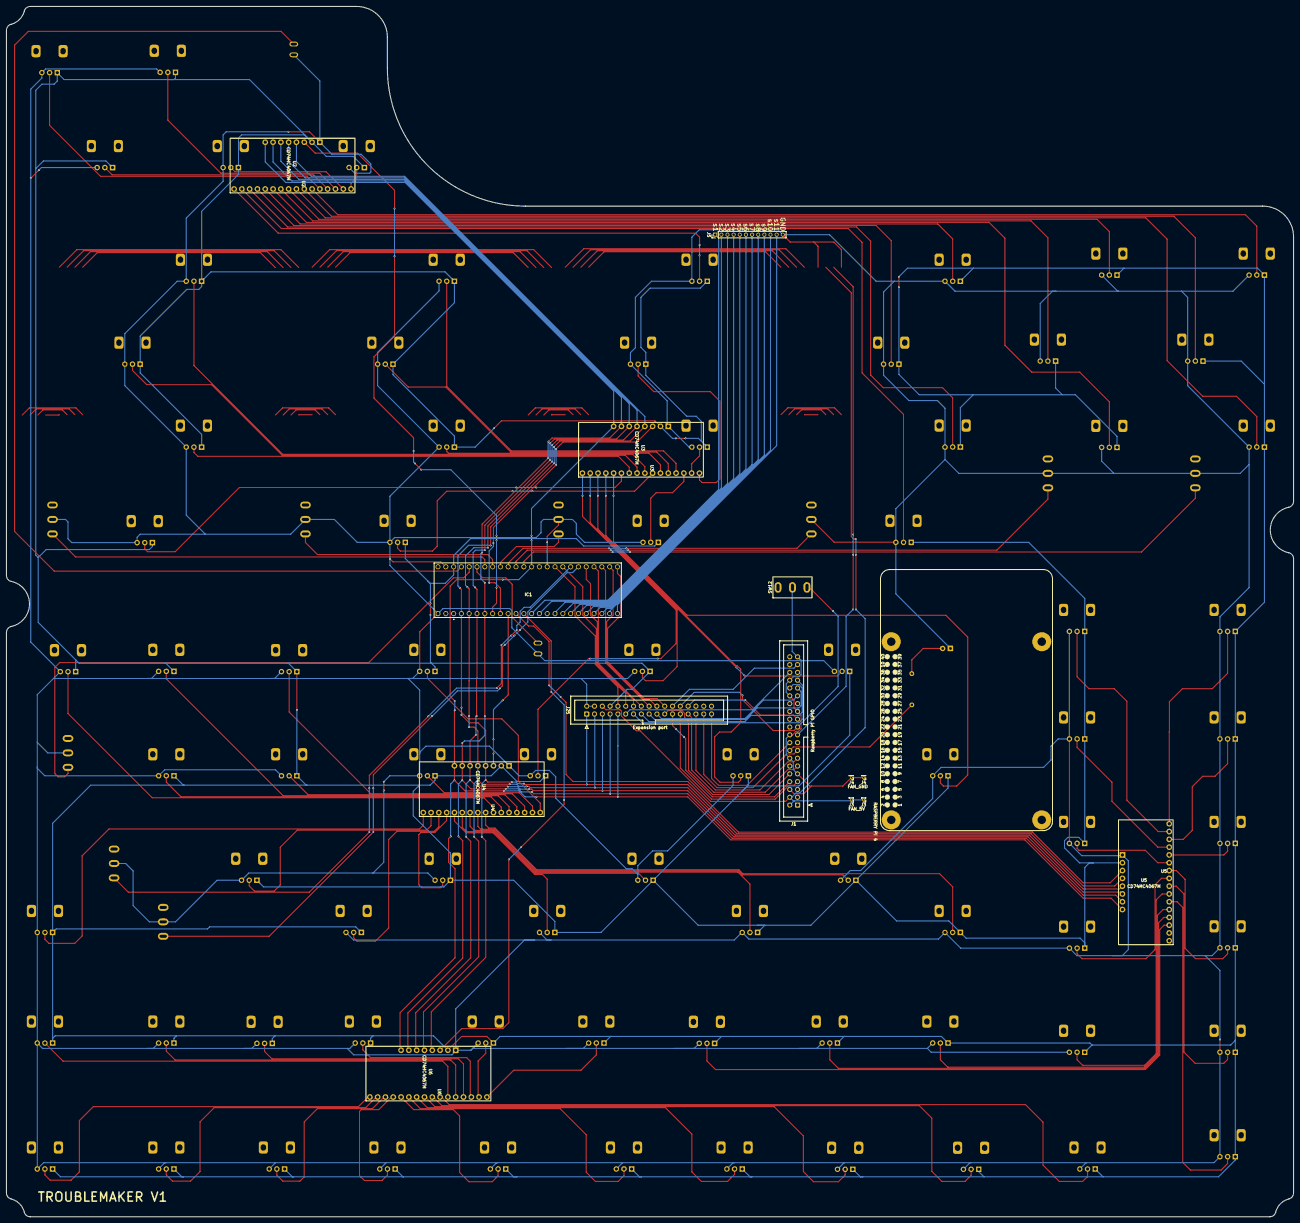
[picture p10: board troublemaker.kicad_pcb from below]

Board: 2 copper layers, 419.0 x 394.0 mm, 115 parts (15 on the bottom side), 166 nets.

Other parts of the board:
J3#2: 5V_RPI2_OR_4; PinHeader_1x01_P1.00mm_Vertical
J4#2: GND_RPI34; PinHeader_1x01_P1.00mm_Vertical
RASPBERRY PI 4: RASPBERRY_PI_4B_4GB; MODULE_RASPBERRY_PI_4B_4GB
Ref**: Val**; TestSilkscreen

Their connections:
XT_GND: J4#2.1; also elsewhere on the board
XT_RPi_5v: J3#2.1; also elsewhere on the board

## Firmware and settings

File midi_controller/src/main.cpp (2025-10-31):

#include <Arduino.h>
#include <Control_Surface.h>

USBMIDI_Interface midi_interface;

//Analog multiplexer on Arduino analog pin A10, enable pin on pin 6
CD74HC4067 mux1 = {
    A0,
    {2, 3, 4, 5},
    6,
};

//Analog multiplexer on Arduino analog pin A10, enable pin on pin 7
CD74HC4067 mux2 = {
    A0,
    {2, 3, 4, 5},
    7,
};

//Analog multiplexer on Arduino analog pin A10, enable pin on pin 8
CD74HC4067 mux3 = {
    A0,
    {2, 3, 4, 5},
    8,
};

//Analog multiplexer on Arduino analog pin A10, enable pin on pin 8
CD74HC4067 mux4 = {
    A0,
    {2, 3, 4, 5},
    9,
};

//Analog multiplexer on Arduino analog pin A10, enable pin on pin 8
CD74HC4067 mux5 = {
    A0,
    {2, 3, 4, 5},
    10,
};

//Sampler controls
Button SamplerStop = {A9};
Button SamplerS1 = {32};
Button SamplerS2 = {31};
Button SamplerS3 = {30};
Button SamplerS4 = {29};
Button SamplerS5 = {28};
Button SamplerS6 = {A13};
Button SamplerS7 = {A12};
Button SamplerS8 = {A11};
Button SamplerS9 = {A10};
Button SamplerS10 = {12};
Button SamplerS11 = {11};
NoteButtons<12> samplerButtons(
    {
        SamplerStop,
        SamplerS1,
        SamplerS2,
        SamplerS3,
        SamplerS4,
        SamplerS5,
        SamplerS6,
        SamplerS7,
        SamplerS8,
        SamplerS9,
        SamplerS10,
        SamplerS11
    },
    {59, Channel_1}, // Adresse MIDI de base
    {1} // Incrément pour chaque bouton
);
CCPotentiometer SamplerSpeed = {mux1.pin(0), {0, Channel_1}};
CCPotentiometer SamplerReverb = {mux1.pin(1), {1, Channel_1}};
CCPotentiometer SamplerDelay = {mux1.pin(2), {2, Channel_1}};
CCPotentiometer SamplerGrain = {mux1.pin(3), {3, Channel_1}};
CCPotentiometer SamplerLevel = {mux1.pin(4), {4, Channel_1}};

//EQ controls
CCButton Eq1Switch = {A1, {0, Channel_2}};
CCPotentiometer Eq1Freq = {mux1.pin(5), {1, Channel_2}};
CCPotentiometer Eq1Gain = {mux1.pin(6), {2, Channel_2}};
CCPotentiometer Eq1Q = {mux1.pin(7), {3, Channel_2}};

CCButton Eq2Switch = {A2, {4, Channel_2}};
CCPotentiometer Eq2Freq = {mux1.pin(8), {5, Channel_2}};
CCPotentiometer Eq2Gain = {mux1.pin(9), {6, Channel_2}};
CCPotentiometer Eq2Q = {mux1.pin(10), {7, Channel_2}};

//Crossover controls
CCButton XSubSwitch = {A3, {0, Channel_3}};
CCPotentiometer XSubAtk = {mux1.pin(11), {1, Channel_3}};
CCPotentiometer XSubRel = {mux1.pin(12), {2, Channel_3}};
CCPotentiometer XSubTresh = {mux1.pin(13), {3, Channel_3}};
CCPotentiometer XSubGain = {mux1.pin(14), {4, Channel_3}};

CCButton XBassSwitch = {A4, {5, Channel_3}};
CCPotentiometer XBassAtk = {mux1.pin(15), {6, Channel_3}};
CCPotentiometer XBassRel = {mux2.pin(0), {7, Channel_3}};
CCPotentiometer XBassTresh = {mux2.pin(1), {8, Channel_3}};
CCPotentiometer XBassGain = {mux2.pin(2), {9, Channel_3}};

CCButton XMidSwitch = {A5, {10, Channel_3}};
CCPotentiometer XMidAtk = {mux2.pin(3), {11, Channel_3}};
CCPotentiometer XMidRel = {mux2.pin(4), {12, Channel_3}};
CCPotentiometer XMidTresh = {mux2.pin(5), {13, Channel_3}};
CCPotentiometer XMidGain = {mux2.pin(6), {14, Channel_3}};

CCButton XHighSwitch = {A6, {15, Channel_3}};
CCPotentiometer XHighAtk = {mux2.pin(7), {16, Channel_3}};
CCPotentiometer XHighRel = {mux2.pin(8), {17, Channel_3}};
CCPotentiometer XHighTresh = {mux2.pin(9), {18, Channel_3}};
CCPotentiometer XHighGain = {mux2.pin(10), {19, Channel_3}};

//Delay controls
CCPotentiometer DelayLFORate = {mux2.pin(11), {0, Channel_4}};
CCPotentiometer DelayLFODepth = {mux2.pin(12), {1, Channel_4}};
CCPotentiometer DelayTime = {mux2.pin(13), {2, Channel_4}};
CCPotentiometer DelayFeedback = {mux2.pin(14), {3, Channel_4}};
CCPotentiometer DelaySampleRate = {mux2.pin(15), {4, Channel_4}};
CCPotentiometer DelayLowCutResonance = {mux3.pin(0), {5, Channel_4}};
CCPotentiometer DelayLowCutFreq = {mux3.pin(1), {6, Channel_4}};
CCPotentiometer DelayHighCutResonance = {mux3.pin(2), {7, Channel_4}};
CCPotentiometer DelayHighCutFreq = {mux3.pin(3), {8, Channel_4}};
CCPotentiometer DelayStereoWidth = {mux3.pin(4), {9, Channel_4}};
CCPotentiometer DelayNoise = {mux3.pin(5), {10, Channel_4}};
CCPotentiometer DelayLevel = {mux3.pin(6), {11, Channel_4}};
CCButton DelayTapTempo = {A7, {12, Channel_4}};
CCButton DelayType = {A8, {13, Channel_4}};

//Grain controls
CCPotentiometer GrainPitch = {mux3.pin(7), {0, Channel_5}};
CCPotentiometer GrainFine = {mux3.pin(8), {1, Channel_5}};
CCPotentiometer GrainSize = {mux3.pin(9), {2, Channel_5}};
CCPotentiometer GrainTexture = {mux3.pin(10), {3, Channel_5}};
CCPotentiometer GrainStretch = {mux3.pin(11), {4, Channel_5}};
CCPotentiometer GrainFeedback = {mux3.pin(12), {5, Channel_5}};
CCPotentiometer GrainShimmer = {mux3.pin(13), {6, Channel_5}};
CCPotentiometer GrainHighCut = {mux3.pin(14), {7, Channel_5}};
CCPotentiometer GrainLevel = {mux3.pin(15), {8, Channel_5}};
CCButton GrainType = {A14, {9, Channel_5}};
CCButton GrainPlayback = {A15, {10, Channel_5}};

//Inputs controls
CCPotentiometer InputAGain = {mux4.pin(0), {0, Channel_6}};
CCPotentiometer InputADelaySend = {mux4.pin(2), {1, Channel_6}};
CCPotentiometer InputAGrainSend = {mux4.pin(4), {2, Channel_6}};
CCPotentiometer InputASubRoarSend = {mux4.pin(6), {3, Channel_6}};
CCPotentiometer InputAReverbSend = {mux4.pin(8), {4, Channel_6}};
// CCPotentiometer InputAAuxSend = {mux4.pin(10), {5, Channel_6}};

//no input b for now, stereo input only
// CCPotentiometer InputBGain = {mux4.pin(1), {6, Channel_12}};
// CCPotentiometer InputBDelaySend = {mux4.pin(3), {7, Channel_13}};
// CCPotentiometer InputBGrainSend = {mux4.pin(5), {8, Channel_14}};
// CCPotentiometer InputBSubRoarSend = {mux4.pin(7), {9, Channel_15}};
// CCPotentiometer InputBReverbSend = {mux4.pin(9), {10, Channel_16}};

//Sub roar controls
CCPotentiometer SubRoarHiCutFreq = {mux4.pin(11), {0, Channel_7}};
CCPotentiometer SubRoarDiode = {mux4.pin(13), {1, Channel_7}};
CCPotentiometer SubRoarEmphasisFreq = {mux5.pin(0), {2, Channel_7}};
CCPotentiometer SubRoarEmphasisGain = {mux5.pin(1), {3, Channel_7}};
CCPotentiometer SubRoarReverbMix = {mux5.pin(2), {4, Channel_7}};
CCPotentiometer SubRoarReverbRoomSize = {mux5.pin(3), {5, Channel_7}};
CCPotentiometer SubRoarReverbDecay = {mux5.pin(4), {6, Channel_7}};
CCPotentiometer SubRoarReverbLowCutFreq = {mux5.pin(4), {7, Channel_7}};
CCPotentiometer SubRoarLevel = {mux5.pin(5), {8, Channel_7}};

//Reverb controls
CCPotentiometer ReverbLowCutFreq = {mux5.pin(6), {0, Channel_8}};
CCPotentiometer ReverbHighCutFreq = {mux5.pin(7), {1, Channel_8}};
CCPotentiometer ReverbDecay = {mux5.pin(8), {2, Channel_8}};
CCPotentiometer ReverbPreDelay = {mux5.pin(9), {3, Channel_8}};
CCPotentiometer ReverbRoomSize = {mux5.pin(10), {4, Channel_8}};
CCPotentiometer ReverbBellResonance = {mux5.pin(11), {5, Channel_8}};
CCPotentiometer ReverbBellFrequency = {mux5.pin(12), {6, Channel_8}};
CCPotentiometer ReverbLFODepth = {mux5.pin(13), {7, Channel_8}};
CCPotentiometer ReverbLFORate = {mux5.pin(14), {8, Channel_8}};
CCPotentiometer ReverbLevel = {mux5.pin(15), {9, Channel_8}};

constexpr analog_t maxRawValue = CCPotentiometer::getMaxRawValue();
constexpr analog_t minimumValue = maxRawValue / 64;
constexpr analog_t maximumValue = maxRawValue - maxRawValue / 64;

analog_t fixDeadZoneAndInvertPot(analog_t raw) {
    // make sure that the analog value is between the minimum and maximum
    raw = constrain(raw, minimumValue, maximumValue);
    // map the value from [minimumValue, maximumValue] to [0, maxRawValue]
    analog_t fixedDeadZone = map(raw, minimumValue, maximumValue, 0, maxRawValue);
    // invert the value
    return maxRawValue - fixedDeadZone;
}

analog_t fixDeadZone(analog_t raw) {
    // make sure that the analog value is between the minimum and maximum
    raw = constrain(raw, minimumValue, maximumValue);
    // map the value from [minimumValue, maximumValue] to [0, maxRawValue]
    return map(raw, minimumValue, maximumValue, 0, maxRawValue);
}

analog_t mapPotForGainControl(analog_t raw) {
    constexpr float scale = 100.0;
    analog_t fixedValue = fixDeadZoneAndInvertPot(raw);
    float normalizedValue = fixedValue / (float)maxRawValue;
    float gainValue = log1p(scale * normalizedValue) / log1p(scale);
    return static_cast<analog_t>(gainValue * maxRawValue);
}

// Received when the midi controller is connected to Sushi
const uint8_t predefinedSysEx[] = {0xF0, 0x7D, 0x01, 0x02, 0x03, 0xF7};
const uint8_t predefinedAnswer[] = {0xF0, 0x7D, 0x02, 0x03, 0x04, 0xF7};

void SendControllerState()
{
    midi_interface.send(predefinedAnswer);
    //send SamplerSpeed message
    SamplerSpeed.forcedUpdate();
    SamplerReverb.forcedUpdate();
    SamplerDelay.forcedUpdate();
    SamplerGrain.forcedUpdate();
    SamplerLevel.forcedUpdate();

    Eq1Switch.update();
    Eq1Freq.forcedUpdate();
    Eq1Gain.forcedUpdate();
    Eq1Q.forcedUpdate();

    Eq2Switch.update();
    Eq2Freq.forcedUpdate();
    Eq2Gain.forcedUpdate();
    Eq2Q.forcedUpdate();

    XSubSwitch.update();
    XSubAtk.forcedUpdate();
    XSubRel.forcedUpdate();
    XSubTresh.forcedUpdate();
    XSubGain.forcedUpdate();

    XBassSwitch.update();
    XBassAtk.forcedUpdate();
    XBassRel.forcedUpdate();
    XBassTresh.forcedUpdate();
    XBassGain.forcedUpdate();

    XMidSwitch.update();
    XMidAtk.forcedUpdate();
    XMidRel.forcedUpdate();
    XMidTresh.forcedUpdate();
    XMidGain.forcedUpdate();

    DelayLFORate.forcedUpdate();
    DelayLFODepth.forcedUpdate();
    DelayTime.forcedUpdate();
    DelayFeedback.forcedUpdate();
    DelaySampleRate.forcedUpdate();
    DelayLowCutResonance.forcedUpdate();
    DelayLowCutFreq.forcedUpdate();
    DelayHighCutResonance.forcedUpdate();
    DelayHighCutFreq.forcedUpdate();
    DelayStereoWidth.forcedUpdate();
    DelayNoise.forcedUpdate();
    DelayLevel.forcedUpdate();
    DelayTapTempo.update();
    DelayType.update();

    GrainPitch.forcedUpdate();
    GrainFine.forcedUpdate();
    GrainSize.forcedUpdate();
    GrainTexture.forcedUpdate();
    GrainStretch.forcedUpdate();
    GrainFeedback.forcedUpdate();
    GrainShimmer.forcedUpdate();
    GrainHighCut.forcedUpdate();
    GrainLevel.forcedUpdate();
    GrainType.update();
    GrainPlayback.update();

    SubRoarHiCutFreq.forcedUpdate();
    SubRoarEmphasisFreq.forcedUpdate();
    SubRoarEmphasisGain.forcedUpdate();
    SubRoarReverbMix.forcedUpdate();
    SubRoarReverbRoomSize.forcedUpdate();
    SubRoarReverbDecay.forcedUpdate();
    SubRoarLevel.forcedUpdate();

    ReverbLowCutFreq.forcedUpdate();
    ReverbHighCutFreq.forcedUpdate();
    ReverbDecay.forcedUpdate();
    ReverbPreDelay.forcedUpdate();
    ReverbRoomSize.forcedUpdate();
    ReverbBellResonance.forcedUpdate();
    ReverbBellFrequency.forcedUpdate();
    ReverbLFODepth.forcedUpdate();
    ReverbLFORate.forcedUpdate();
    ReverbLevel.forcedUpdate();

    InputAGain.forcedUpdate();
    InputADelaySend.forcedUpdate();
    InputAGrainSend.forcedUpdate();
    InputASubRoarSend.forcedUpdate();
    InputAReverbSend.forcedUpdate();

    //TODO: Implement input B
}

// Custom MIDI callback that prints incoming SysEx messages.
struct MyMIDI_Callbacks : MIDI_Callbacks {

    // This callback function is called when a SysEx message is received.
    void onSysExMessage(MIDI_Interface &, SysExMessage sysex) override {
        // Print the message
        if (sysex.length == sizeof(predefinedSysEx) &&
            memcmp(sysex.data, predefinedSysEx, sizeof(predefinedSysEx)) == 0) {
            // Send state
            SendControllerState();
        }
    }

} callback {};

void setup()
{
    Control_Surface.begin();
    samplerButtons.begin();

    midi_interface.begin();
    midi_interface.setCallbacks(callback);

    SamplerSpeed.map(fixDeadZoneAndInvertPot);
    SamplerReverb.map(mapPotForGainControl);
    SamplerDelay.map(mapPotForGainControl);
    SamplerGrain.map(mapPotForGainControl);
    SamplerLevel.map(fixDeadZoneAndInvertPot);

    Eq1Freq.map(fixDeadZoneAndInvertPot);
    Eq1Gain.map(fixDeadZoneAndInvertPot);
    Eq1Q.map(fixDeadZoneAndInvertPot);
    Eq2Freq.map(fixDeadZoneAndInvertPot);
    Eq2Gain.map(fixDeadZoneAndInvertPot);
    Eq2Q.map(fixDeadZoneAndInvertPot);

    XSubSwitch.invert();
    XSubAtk.map(fixDeadZoneAndInvertPot);
    XSubRel.map(fixDeadZoneAndInvertPot);
    XSubTresh.map(fixDeadZoneAndInvertPot);
    XSubGain.map(fixDeadZoneAndInvertPot);
    XBassSwitch.invert();
    XBassAtk.map(fixDeadZoneAndInvertPot);
    XBassRel.map(fixDeadZoneAndInvertPot);
    XBassTresh.map(fixDeadZoneAndInvertPot);
    XBassGain.map(fixDeadZoneAndInvertPot);
    XMidSwitch.invert();
    XMidAtk.map(fixDeadZoneAndInvertPot);
    XMidRel.map(fixDeadZoneAndInvertPot);
    XMidTresh.map(fixDeadZoneAndInvertPot);
    XMidGain.map(fixDeadZoneAndInvertPot);
    XHighSwitch.invert();
    XHighAtk.map(fixDeadZoneAndInvertPot);
    XHighRel.map(fixDeadZoneAndInvertPot);
    XHighTresh.map(fixDeadZoneAndInvertPot);
    XHighGain.map(fixDeadZoneAndInvertPot);

    DelayLFORate.map(fixDeadZoneAndInvertPot);
    DelayLFODepth.map(fixDeadZoneAndInvertPot);
    DelayTime.map(fixDeadZone);
    DelayFeedback.map(fixDeadZoneAndInvertPot);
    DelaySampleRate.map(fixDeadZoneAndInvertPot);
    DelayLowCutFreq.map(fixDeadZoneAndInvertPot);
    DelayLowCutResonance.map(fixDeadZoneAndInvertPot);
    DelayHighCutResonance.map(fixDeadZoneAndInvertPot);
    DelayHighCutFreq.map(fixDeadZoneAndInvertPot);
    DelayStereoWidth.map(fixDeadZoneAndInvertPot);
    DelayNoise.map(fixDeadZoneAndInvertPot);
    DelayLevel.map(fixDeadZoneAndInvertPot);

    GrainPitch.map(fixDeadZoneAndInvertPot);
    GrainFine.map(fixDeadZoneAndInvertPot);
    GrainSize.map(fixDeadZoneAndInvertPot);
    GrainTexture.map(fixDeadZoneAndInvertPot);
    GrainStretch.map(fixDeadZoneAndInvertPot);
    GrainFeedback.map(fixDeadZoneAndInvertPot);
    GrainShimmer.map(fixDeadZoneAndInvertPot);
    GrainHighCut.map(fixDeadZoneAndInvertPot);
    GrainLevel.map(fixDeadZoneAndInvertPot);
    GrainType.invert();
    GrainPlayback.invert();

    SubRoarHiCutFreq.map(mapPotForGainControl);
    SubRoarEmphasisFreq.map(fixDeadZoneAndInvertPot);
    SubRoarEmphasisGain.map(fixDeadZoneAndInvertPot);
    SubRoarReverbMix.map(fixDeadZoneAndInvertPot);
    SubRoarReverbRoomSize.map(fixDeadZoneAndInvertPot);
    SubRoarReverbDecay.map(fixDeadZoneAndInvertPot);
    SubRoarLevel.map(fixDeadZoneAndInvertPot);

    ReverbLowCutFreq.map(fixDeadZoneAndInvertPot);
    ReverbHighCutFreq.map(fixDeadZoneAndInvertPot);
    ReverbDecay.map(fixDeadZoneAndInvertPot);
    ReverbPreDelay.map(fixDeadZoneAndInvertPot);
    ReverbRoomSize.map(fixDeadZoneAndInvertPot);
    ReverbBellResonance.map(fixDeadZoneAndInvertPot);
    ReverbBellFrequency.map(fixDeadZoneAndInvertPot);
    ReverbLFODepth.map(fixDeadZoneAndInvertPot);
    ReverbLFORate.map(fixDeadZoneAndInvertPot);
    ReverbLevel.map(fixDeadZoneAndInvertPot);

    InputAGain.map(fixDeadZoneAndInvertPot);
    InputADelaySend.map(mapPotForGainControl);
    InputAGrainSend.map(mapPotForGainControl);
    InputASubRoarSend.map(mapPotForGainControl);
    InputAReverbSend.map(mapPotForGainControl);

    Serial.begin(115200);
}

void loop()
{
    Control_Surface.loop();
    samplerButtons.update();
}

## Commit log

2024-10-09 notes and volts lots of pots code adapted to current prototype
2024-10-09 replaced use of MIDI.h with MIDIUSB.h
    [main.cpp]
2024-10-09 trying to figure out why the teensy reboot-loops, using vanilla MidiUSB
    [main.cpp]
2024-10-10 fixed warnings trying with only 8 pots
    [main.cpp]
2024-10-10 Now using Control Surface, 16 pots prototype works
2024-10-15 EQ+Xover prototype code
2024-10-21 kicad schematics v0.1
    [troublemaker.kicad_pcb, troublemaker.kicad_sch]
2024-10-21 Added taptempo led, now using SnapEDA teensy and rpi schemes and footprints
    [troublemaker.kicad_sch]
2024-10-22 Added missing stuff on schematic, PCB layout WIP
    [troublemaker.kicad_pcb, troublemaker.kicad_sch]
2024-10-22 added pcb autosave to gitignore
2024-10-22 Fixed some issues with the PCB
    [troublemaker.kicad_pcb]
2024-10-22 Added Fusion360 design file (WIP)
    [Faiseur de trouble v4.f3z]
2024-10-23 Fixed IC footprints having edge cuts
    [troublemaker.kicad_pcb]
2024-10-23 JLCPCB DRC, pots are connected to muxers, rearranged scheme, added missing LED resistor and pin header
    [troublemaker.kicad_pcb, troublemaker.kicad_sch]
2024-10-24 GND + 3v3 connections
    [troublemaker.kicad_pcb]
2024-10-24 Added symbols and footprints
    [troublemaker.kicad_sch]
2024-10-24 small routing fixes, saved project file after changing lib paths
    [troublemaker.kicad_pcb]
2024-10-24 Working on routing the muxers
    [troublemaker.kicad_pcb]
2024-10-26 All connections done
    [troublemaker.kicad_pcb, troublemaker.kicad_sch]
2024-10-26 Fixed DRC errors
    [troublemaker.kicad_pcb]
2024-10-26 fixed missing connections
    [troublemaker.kicad_pcb]
2024-10-26 Removed pads from RPI footprint, added some text to jumpers
    [troublemaker.kicad_pcb]
2024-10-27 Removed capacitors as I already have them on the breakout board. Small reroutes.
    [troublemaker.kicad_pcb, troublemaker.kicad_sch]
2024-10-27 updated enclosure design
    [Faiseur de trouble v4.f3z]
2024-10-28 added expansion port and GPIO socket
    [troublemaker.kicad_pcb, troublemaker.kicad_sch]
2024-10-29 added mooncrown logo
    [troublemaker.kicad_pcb, troublemaker.kicad_sch]
2024-10-29 Cleaned PCB traces
    [troublemaker.kicad_pcb]
2024-10-29 Last PCB finishes and cleanups, added gerber files
    [troublemaker-B_Cu.gbr, troublemaker-B_Mask.gbr, troublemaker-B_Silkscreen.gbr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]
2024-11-17 PCB midi controller code (to be tested)
2024-11-17 PCB midi controller code refactor
2024-11-17 Fixed muxers signal pin and button type
    [main.cpp]
2024-11-18 Fixed sampler buttons being CC
    [main.cpp]
2024-11-19 Inverted pots and xover switches
    [main.cpp]
2024-11-21 Some midi & mapping fixes, added echo lowcut
    [main.cpp]
2024-11-21 Fixed echo filter, remapped eq ranges
2024-11-21 Added echo filter, various mapping fixes
    [main.cpp]
2025-01-15 Fixed bad config Back to old method for pots controlling my own gain plugin
    [main.cpp]
2025-01-17 Fixed echo filter bad midi mapping
2025-01-17 MIDI Controller now reacts to sysex message "F0 7D 01 02 03 F7" and sends current state in a burst of midi messages
2025-10-31 Sushi Config - add Master track, with EQ proof of concept (will be replaced with a custom VST)
2025-10-31 Mapped tap tempo button
